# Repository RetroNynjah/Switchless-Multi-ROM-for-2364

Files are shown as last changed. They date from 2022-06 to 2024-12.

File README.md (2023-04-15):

# Retroninja Switchless Multi-ROM for 2364 ROMs

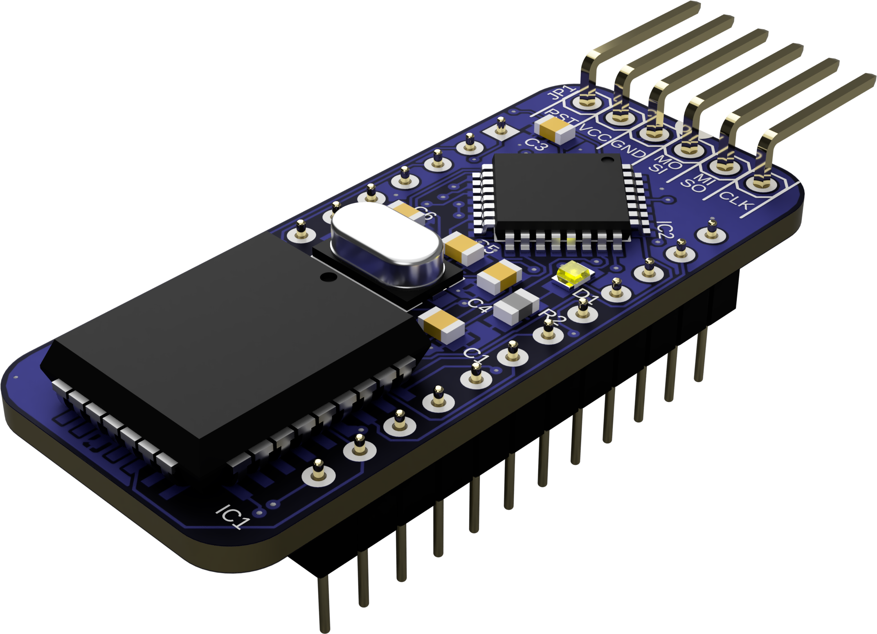
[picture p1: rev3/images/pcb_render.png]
3D rendering
<br/>

A switchless multi-ROM for 2364 ROM (24-pin) type applications. The switch is controlled by an MCU that is picking up predefined magic words on the data bus.  
This is a more generic and further developed version of my previous 1541 Multi-ROM design.

Example use cases:
* ROM switch for the Commodore 1541 disk drive controlled by DOS commands.
* Menu driven Kernal switch for Commodore C64 (longboards)
* Menu driven Kernal switch for Commodore VIC-20
* You tell me

Check the Applications folder for examples on how to use it for the use cases above.

Check the Technical Guide for a general technical description, build instructions and BOM.

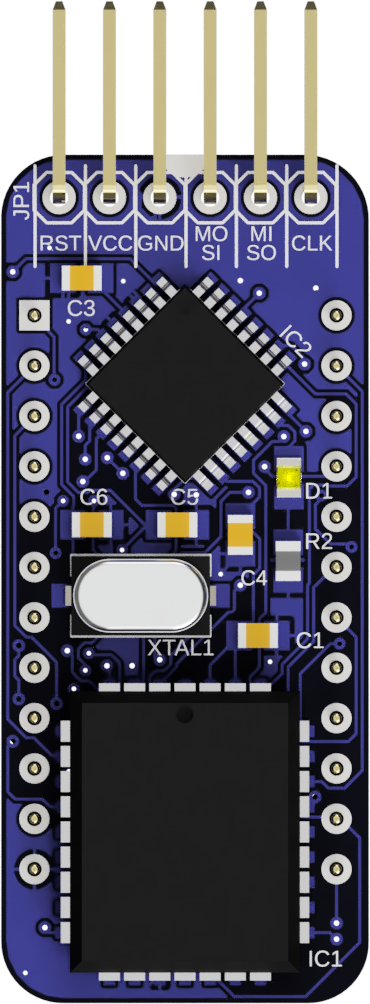
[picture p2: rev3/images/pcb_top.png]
Rendered top view
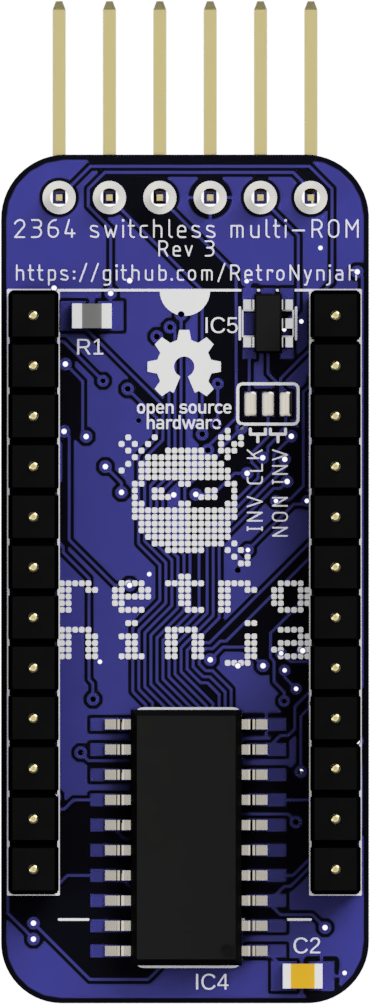
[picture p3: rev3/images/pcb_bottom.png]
Rendered bottom view
  <br/>

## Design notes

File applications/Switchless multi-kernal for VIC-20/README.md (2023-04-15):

# Switchless multi-kernal for VIC-20

Can be used as a Kernal switch for the VIC-20.  
The Kernal menu is activated by pressing the RESTORE key for a few seconds.

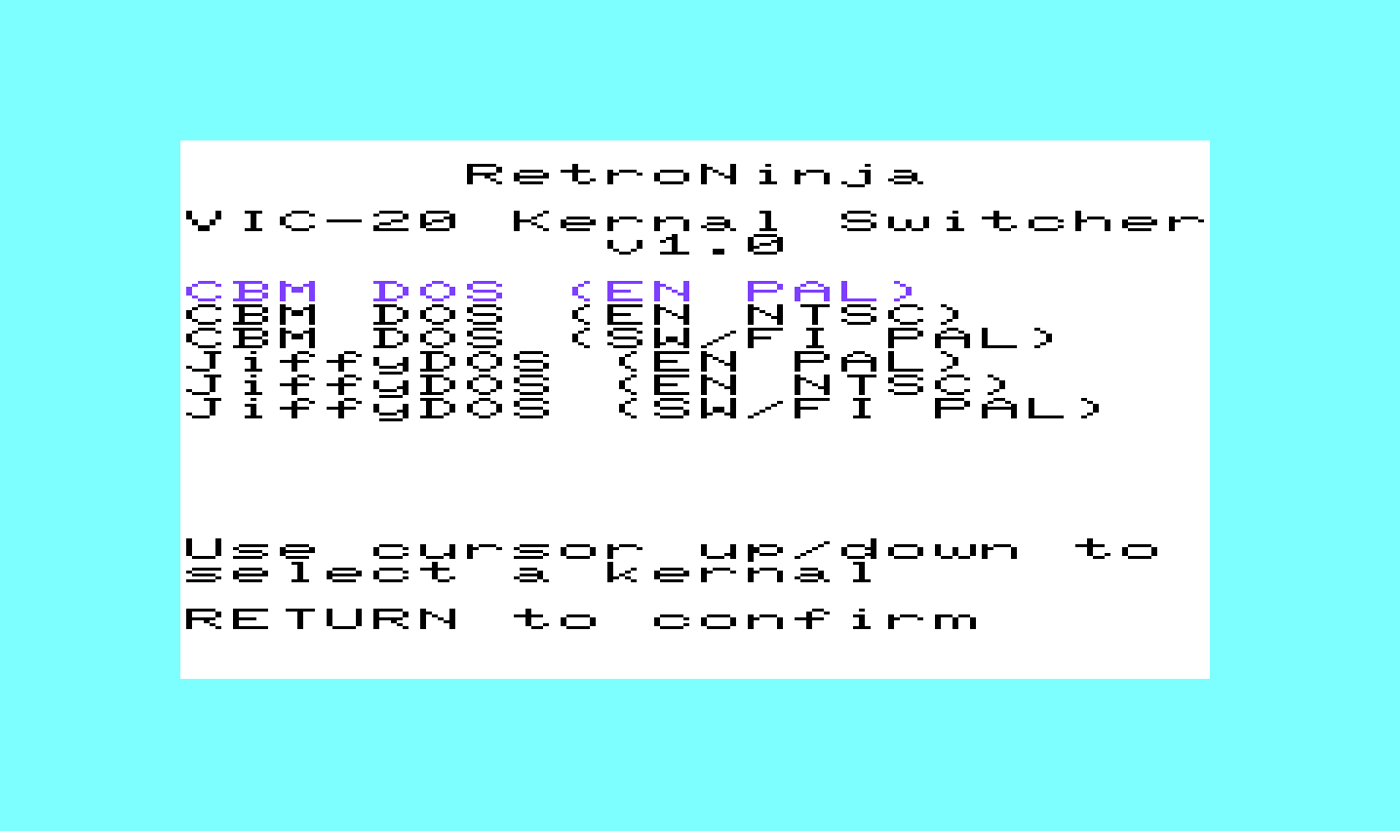
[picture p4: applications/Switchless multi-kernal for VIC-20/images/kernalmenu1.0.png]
VIC-20 Kernal menu
<br/>

Read more in the User's Guide

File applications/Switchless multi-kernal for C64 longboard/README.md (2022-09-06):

# Switchless multi-kernal for C64 longboard

Can be used as a Kernal switch for the C64 longboard motherboards.  
The Kernal menu is activated by pressing the RESTORE key for a few seconds.

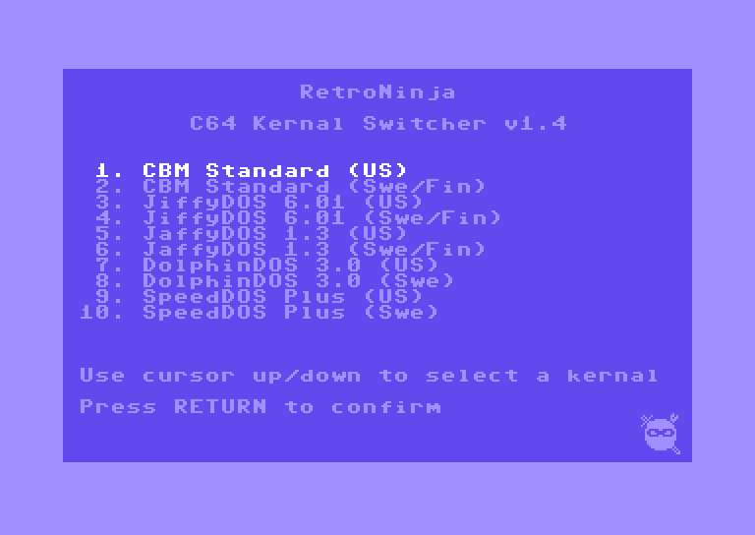
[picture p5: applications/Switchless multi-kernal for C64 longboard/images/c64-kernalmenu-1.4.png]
C64 Kernal menu
<br/>

Read more in the User's Guide

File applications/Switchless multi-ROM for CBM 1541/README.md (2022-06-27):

# Switchless multi-ROM for CBM 1541
Switches DOS ROM on the 1541 and other CBM IEC drives that uses 2364 ROMs. Can be used to switch ROM between CBM DOS/JiffyDOS/SpeedDOS/DolphinDOS and so on.

The switch is controlled by sending a command like *LOAD "2@RNROM",8* from the computer to switch to drive ROM image 2.

Read more in the User's guide.

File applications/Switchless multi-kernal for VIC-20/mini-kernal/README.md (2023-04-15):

# VIC-20 Mini-Kernal

This is the assembly source code for the VIC-20 Mini-Kernal.  
The project was created in CBM prg Studio

You need to adjust the menu to fit your needs and compile the Mini-Kernal yourself unless you are going with the exact same Kernals I did.  
Tested on both PAL and NTSC systems  

## Disclaimer:  
I'm not an assembly programmer which you should be able to tell by looking at the source. If the code doesn't work for you feel free to fix it,
If anyone wants to have a go at improving and optimizing the code you are free to do so too.

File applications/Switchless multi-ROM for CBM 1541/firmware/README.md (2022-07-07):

# Firmware

The firmware directory contains source code along with some precompiled hex files for the microcontroller.

The source code is written using the Arduino environment and can be flashed directly from Arduino using an ISP programmer.

Change log:  
1.0 - First public version for the old 1541 Multi-ROM board (rev 1, rev 1.1 & rev 2 boards) 14 May 2021  
1.1 - Updated sketch to suite the 2364 Multi-ROM board (rev 3 boards) 7 July 2022

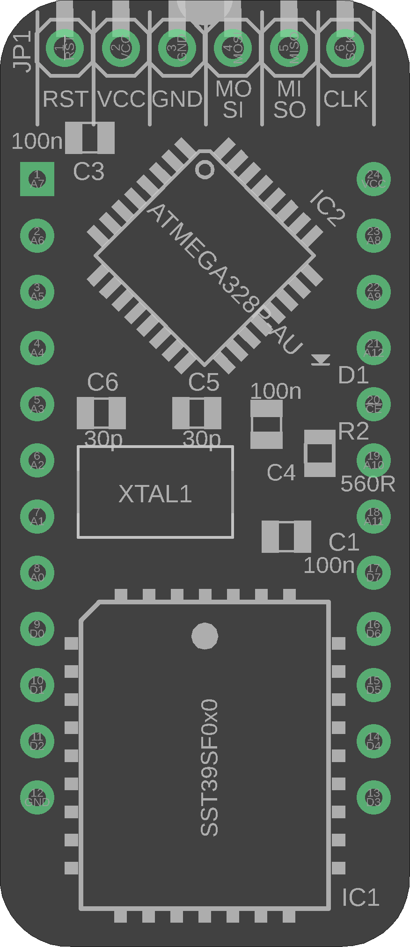
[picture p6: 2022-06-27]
rev3/images/place_top_cropped.png

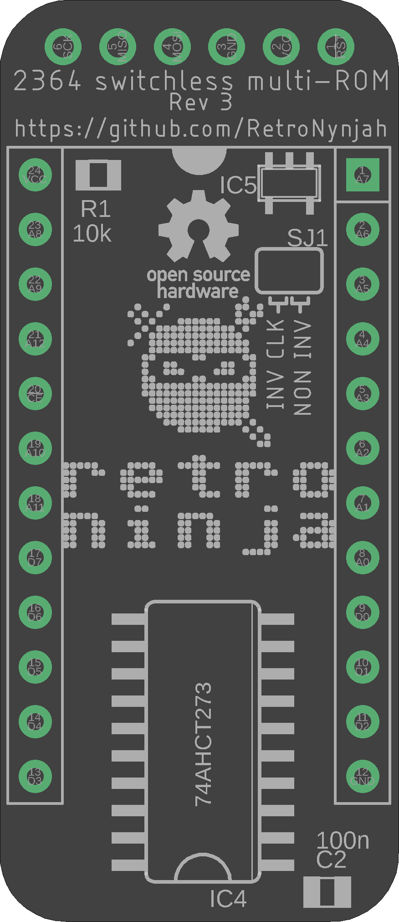
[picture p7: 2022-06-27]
rev3/images/place_bottom_cropped.png

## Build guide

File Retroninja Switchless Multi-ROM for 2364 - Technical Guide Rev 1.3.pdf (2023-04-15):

# Retroninja Switchless Multi-ROM for 2364

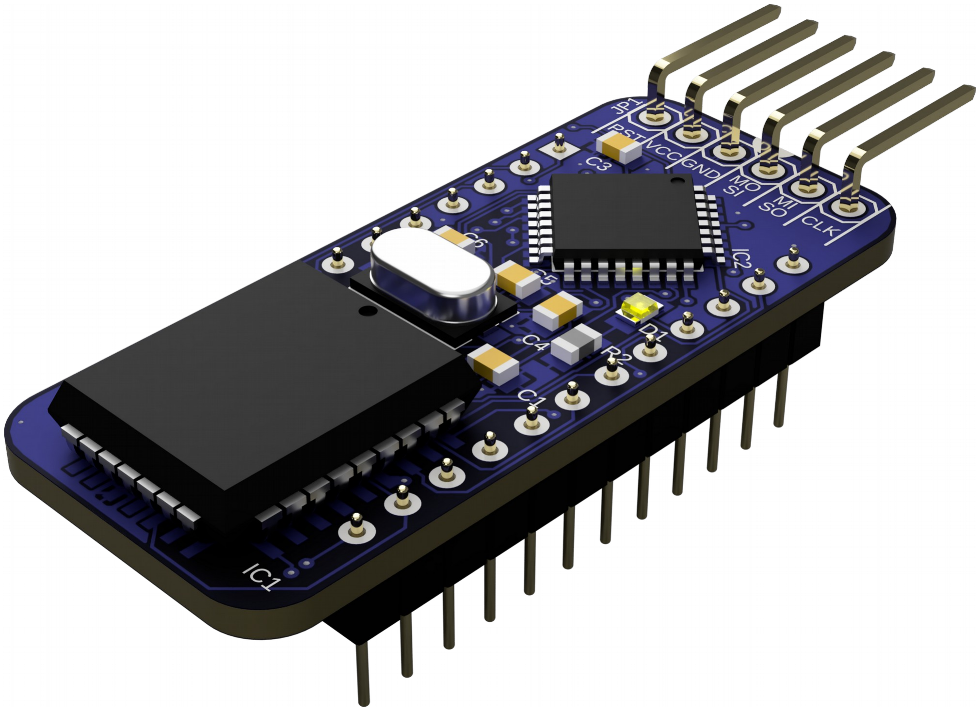
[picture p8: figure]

# Technical Guide

Retroninja Switchless Multi-ROM for 2364 | Technical Guide Version 1.3

## Table of Contents

# Background

I first created this ROM switcher as a DOS ROM switcher for the Commodore 1541 disk drive which in turn was derived from a Commodore 1541-II drive ROM switch that I had previously designed.
I realized that it can be used for a lot of other equipment that is using similar ROMs so it was re-branded and modified making the clock inverter optional.

# Theory of operation

The circuit is meant to sit in a ROM socket instead of a 24-pin 2364 ROM.
The AVR microcontroller (MCU) is connected to the data pins of the ROM socket through a flip-flop that latches the data to give the MCU more time to read the data. It's also connected to some header pins that can be connected to a clock source, a reset line and optionally other signals. It also has an on-board flash chip that contains multiple ROM images.
With the help of an external clock source, the MCU can capture bytes that are passing on the data bus and react to a predefined string of ”magic bytes” by switching the upper address pins on the flash circuit to switch to a different ROM image.
The flip-flop triggers on positive-edge of clock and if data is arriving on the bus at the negative edge of the clock signal then the clock source needs to be inverted for the flip-flop to latch the data correctly. This can be done by installing the inverter gate at IC5 and configuring solder jumper SJ1 for inverted clock.
The need for this differs between implementations depending on how the magic bytes ends up on the bus. The address pins above A12 (A13-A18) are controlled by the MCU which gives a maximum of 64*8KByte switchable ROMs.
An onboard LED can be used for diagnostic blinking or other feedback.

# Usage examples

The two use cases I've used it in is for switching JiffyDOS ROM in Commodore disk drives and Kernal in the Commodore 8-bit computers but it should be usable for other things too.

Commodore 1541 DOS ROM Switcher
The MCU source code for the 1541 ROM switch can be found under samples in the GitHub repository at: https://github.com/RetroNynjah/Switchless-Multi-ROM-for-2364
At power on, the MCU in the ROM switcher reads address 0 from its internal EEPROM to find out which ROM it should select, sets the A13-A18 address pins on the flash chip accordingly and resets the drive to make sure it’s booted with the correct image. This can be noticed when the drive is powered on and the drive initializes and stops spinning and then spins up again briefly during the switch reset.
It then starts listening for a switch command.
Even at a clock speed of 16 MHz, reading and analyzing data on a 1MHz data bus can be a challenge so the data on the 1541 data bus is buffered in the switcher by a 74AHCT273 flip-flop that is clocked by the Write signal on the 6502 MPU in the 1541. By clocking the data with the R/W signal we filter out irrelevant bus traffic and the flip-flop holds the relevant data until the next R/W cycle. This gives the MCU a little more time to read the data from the flip-flop.
The MCU listens for a predefined sequence of bytes in reverse order (MORNR@) and once the sequence is found, it treats the following numeric character as the target ROM image number. The reverse order of the characters on the bus is why the image number must be specified at the beginning of the command.

The MCU sets address pins A13-A18 on the flash chip according to image selection and it stores the ROM number at address 0 of its internal EEPROM for use at next power-on. It then resets the drive by toggling the IEC reset line.
The command can be sent from basic on a computer such as C64 or C128 by utilizing any disk drive command that contains text strings such as:

The LOAD command in the example will return a file not found error but you should see the drive switch ROM and perform a drive reset. The ROM switch LED will blink 2 times to indicate that image 2 was selected.
When building a 1541 ROM switch you should bridge the solder jumper like this:
SJ1
Inverted Clock | Non-inverted Clock

Note: To invert clock we must also install IC5

Some pins on the switch needs to be connected to the right signals in the drive. These signals can be connected to the drive using test clips but to have a secure installation it's better to solder the cables to the bottom of the PCB.
Switch pin | Drive signal
CLK | R/W (6502 pin 34)
MOSI | RESET (Middle pin of IEC DIN connector)

This switch only suits the 1541 and clones that has 24-pin ROM sockets.
1541C/1541-II drives and some clones have 28-pin 27128 type ROMs. I have another Multi-ROM version that is compatible with those in the following repository: https://github.com/RetroNynjah/Switchless-Multi-ROM-for-27128-27256

Commodore 64 longboard menu-driven Kernal switch
The MCU source code and Mini-Kernal source code for the C64 longboard kernal switch can be found under applications in the GitHub repository at:
https://github.com/RetroNynjah/Switchless-Multi-ROM-for-2364
At power on, the MCU in the Kernal switch reads address 0 from its internal EEPROM to find out which Kernal it should select, sets the A13-A18 address pins on the flash chip accordingly and resets the computer to make sure it’s booted with the correct image.
If at any time, restore is pressed and held for a few seconds the MCU will detect this and switch to Kernal 0 which is a menu Kernal. For this application I created a custom Mini-Kernal for the C64 that displays a list of Kernals to choose from.

LOAD “2@RNROM”,8

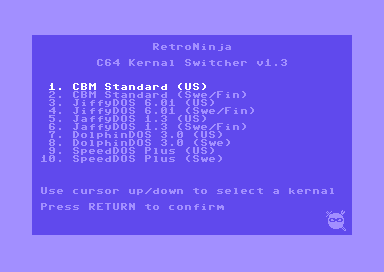
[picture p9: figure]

When the user selects a Kernal image from the menu, the Mini-Kernal writes a predefined switching command to RAM along with a byte that indicates the selected image number. It does this over and over. Example of the command: RNROM64#1 where 1 is a byte with value 0x01 that tells the switch that we want to switch to kernal image 1.
The Kernal switch now captures the command from the data bus, writes the selected kernal number to the MCU EEPROM for future use, then it switches the address pins A13-A18 accordingly. It then pulls the reset line briefly to make the computer restart using the new Kernal. The computer will continue to start up using this Kernal until a new choice is made.
The flash is populated with the Mini-Kernal followed by up to 10*8 KB Kernals. It would in theory be possible to add up to 63 kernals if both the Mini-Kernal and the MCU firmware was modified in some way to accommodate that many Kernal images.
Here's an example layout that fills out an SST39SF010A:

If the same layout would be used with a larger flash chip it should be duplicated to fill out the flash. When building a C64 kernal switch you should bridge the solder jumpers like this:
SJ1
Inverted Clock | Non-inverted Clock

Note: As we don't invert the clock we don't need to install IC5

Some pins on the switch needs to be connected to the right signals in the computer. These signals can be connected to various ICs in the computer using test clips but to have a secure installation it's better to solder the cables to vias on the PCB. See pictures in the samples directory of the GitHub repository.
Switch pin | Computer signal
CLK | R/W
MISO | RESTORE
MOSI | RESET
Mini-Kernal | CBM Kernal | JiffyDOS US | JiffyDOS SE | JiffyDOS DK | JaffyDOS US | JaffyDOS SE | SpeedDOS | SpeedDOS | DolphinDOS | DolphinDOS | Mini-Kernal | Mini-Kernal | Mini-Kernal | Mini-Kernal | Mini-Kernal
8kB | 8kB | 8kB | 8kB | 8kB | 8kB | 8kB | 8kB | 8kB | 8kB | 8kB | 8kB | 8kB | 8kB | 8kB | 8kB

This C64 Kernal switch only suits the C64 longboards which have a 24pin ROM and has basic in a separate ROM. All C64 motherboards are longboards except for PCB 250469 which can be found in newer C64C's. The C64 shortboard (PCB 250469) have 28-pin 27128 type Kernal ROMs and I have another Multi-ROM version that is compatible with those in the following repository: https://github.com/RetroNynjah/Switchless-Multi-ROM-for-27128-27256

Commodore VIC-20 menu-driven Kernal switch
The MCU source code and Mini-Kernal source code for the VIC-20 kernal switch can be found under applications in the GitHub repository at:
https://github.com/RetroNynjah/Switchless-Multi-ROM-for-2364
At power on, the MCU in the Kernal switch reads address 0 from its internal EEPROM to find out which Kernal it should select, sets the A13-A18 address pins on the flash chip accordingly and resets the computer to make sure it’s booted with the correct image.
If at any time, restore is pressed and held for a few seconds the MCU will detect this and switch to Kernal 0 which is a menu Kernal. For this application I created a custom Mini-Kernal for the VIC-20 that displays a list of Kernals to choose from.

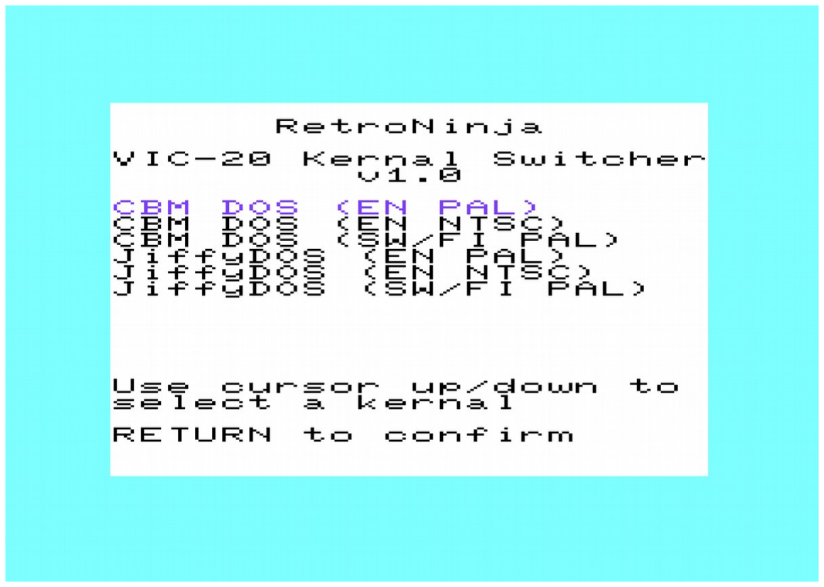
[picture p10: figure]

When the user selects a Kernal image from the menu, the Mini-Kernal writes a predefined switching command to RAM along with a byte that indicates the selected image number. It does this over and over. Example of the command: RNROM20#1 where 1 is a byte with value 0x01 that tells the switch that we want to switch to kernal image 1.
The Kernal switch now captures the command from the data bus, writes the selected kernal number to the MCU EEPROM for future use, then it switches the address pins A13-A18 accordingly. It then pulls the reset line briefly to make the computer restart using the new Kernal. The computer will continue to start up using this Kernal until a new choice is made.
The flash is populated with the Mini-Kernal followed by up to 10*8 KB Kernals. It would in theory be possible to add up to 63 kernals if both the Mini-Kernal and the MCU firmware was modified in some way to accommodate that many Kernal images.
Here's an example layout that fills out an SST39SF010A:

If the same layout would be used with a larger flash chip it should be duplicated to fill out the flash.

Mini-Kernal | CBM EN PAL | CBM EN NTSC | CBM SE PAL | Jiffy EN PAL | Jiffy EN NTSC | Jiffy SE PAL | Mini-Kernal | Mini-Kernal | Mini-Kernal | Mini-Kernal | Mini-Kernal | Mini-Kernal | Mini-Kernal | Mini-Kernal | Mini-Kernal
8kB | 8kB | 8kB | 8kB | 8kB | 8kB | 8kB | 8kB | 8kB | 8kB | 8kB | 8kB | 8kB | 8kB | 8kB | 8kB

When building a VIC-20 kernal switch you should bridge the solder jumpers like this: SJ1
Inverted Clock | Non-inverted Clock

Note: As we don't invert the clock we don't need to install IC5

Some pins on the switch needs to be connected to the right signals in the computer. These signals can be connected to various ICs in the computer using test clips but to have a secure installation it's better to solder the cables to vias on the PCB. See pictures in the samples directory of the GitHub repository.
Switch pin | Computer signal
CLK | R/W
MISO | RESTORE
MOSI | RESET

# Assembling the module

The PCB is small and a bit difficult to solder but it can be hand soldered. The reason for the small size is space constraints in some Commodore drives that this module was designed for originally. Other drives any devices may have the same constraints so keeping it small is good for compatibility.
The flash chip (PLCC) is the trickiest part to solder and If you find it hard to hand solder I recommended reflow soldering the top side using stencil and solder paste. Then solder the bottom side by hand and finally solder the pin headers.
There is a solder jumper on the bottom that must be configured.
If you configure SJ1 for inverted clock then you must also install IC5. Otherwise you can leave it out. It will only be used when SJ1 is configured for inverted clock.
Note: Don't forget to program the flash before soldering!

# Parts

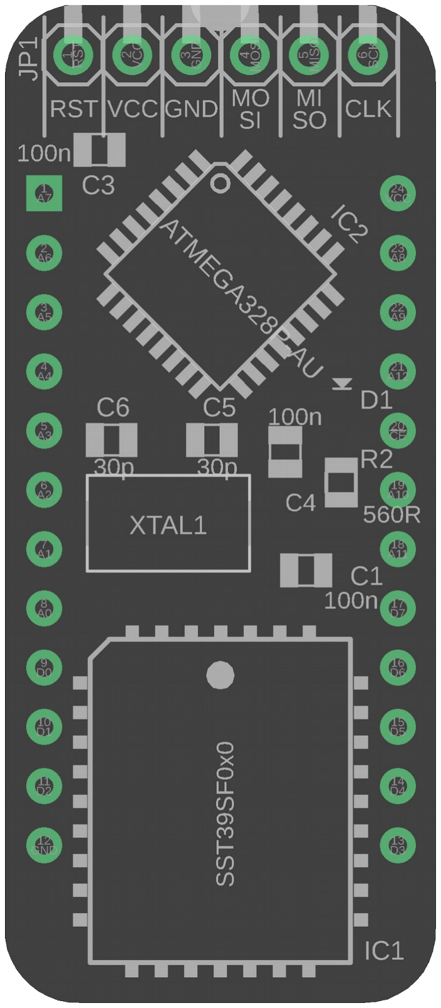
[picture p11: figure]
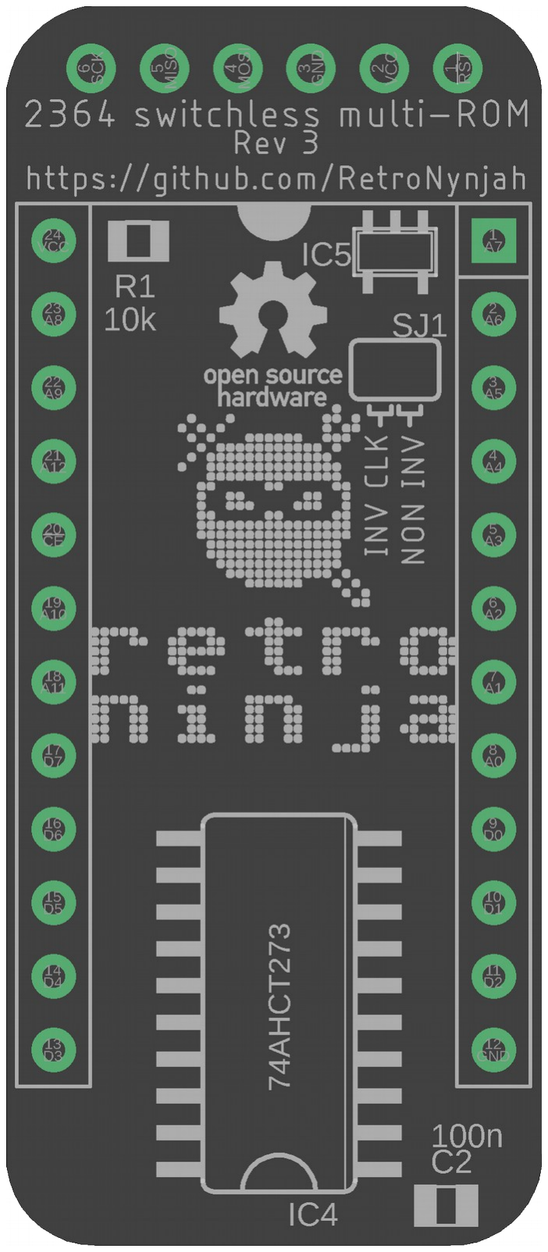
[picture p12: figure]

Top side is to the left, bottom side is to the right.
Component | Part | Description | Comment
JP1 | Header | 6-pin right-angle
D1 | LED | 0805 LED
C1, C2, C3,C4 | 100nF capacitor | 0805 ceramic capacitor
C5, C6 | 30pF capacitor | 0805 ceramic capacitor | 22pF works fine too
XTAL1 | ECS-160-20-3X-TR | 16MHz Crystal 7.0x4.1 mm
R1 | 10kΩ resistor | 0805 Resistor
R2 | 560Ω resistor | 0805 Resistor
IC1 | SST39SF0x0 | 32-PLCC Flash 4.5-5.5V | SST39SF010/20/40
IC2 | ATmega MCU | 32-TQFP MCU | Atmega48/88/168/328
IC3 | Headers | 2 header rows, 14 pin | Use machined or flat pins - not square
IC4 | 74AHCT273 | 20-SOIC 5.3mm Flip-Flop
IC5 | 741G04 | SOT23-5 1 x Inverter | Only needed if clock needs inverting
The ATmega model is not critical. The firmware requires less than 2KB of MCU flash. I have tested Atmega48, 48A, 48PA, 88A, 328P and they have worked for me. Any other pin-compatible ATmega could work too depending on your application.

# Programming the microcontroller

The firmware can be flashed using the 6-pin ISP header. The source code is written for Arduino and programming the firmware can be done directly from the Arduino IDE using an ISP programmer.
If you are using an Atmega328 it can be programmed as an Arduino UNO. The other variants require custom board definitions. I have used the MiniCore from MCUdude (https://github.com/MCUdude/MiniCore) with default board settings.
If you can't or don't want to use Arduino I have some precompiled hex files for the Kernal switch and drive ROM switch along with fuse configurations and syntax examples for how to program them using avrdude. These can be found under the Examples folder in my GitHub repository.

# Programming the flash chip (ROM)

The flash chip needs to be programmed before soldering it. If you need to reprogram the flash later it must first be desoldered and then resoldered again after reprogramming.
You need to concatenate all your images into one file and fill up any empty space in flash with valid extra images to avoid bricking your host device if an incorrect image number is selected. If that would happen the EEPROM can be reset by re-flashing the firmware.
All images must be 8kB in size.

# Document revision history

1.0 Initial version
1.1 Cover page image corrected
1.2 BOM Corrected
1.3 VIC-20 Kernal switch section added

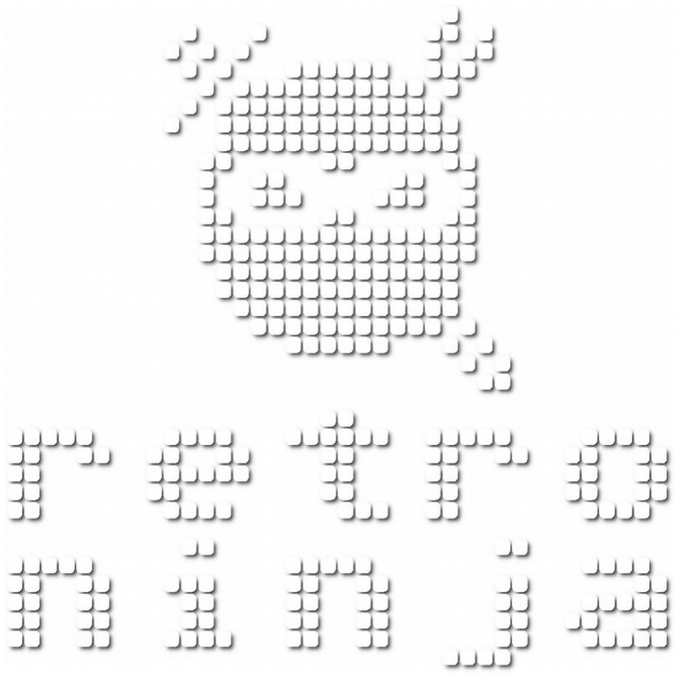
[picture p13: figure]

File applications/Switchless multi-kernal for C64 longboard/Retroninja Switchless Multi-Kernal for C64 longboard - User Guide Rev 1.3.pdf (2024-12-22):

# Retroninja Switchless Multi-Kernal for C64 longboard

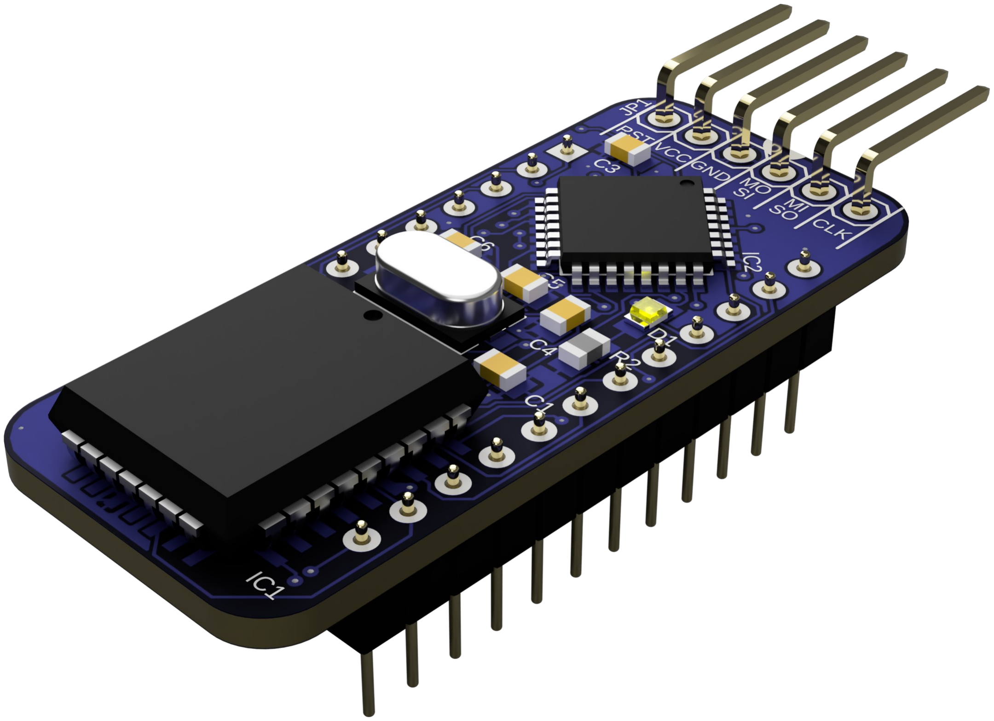
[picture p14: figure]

# User Guide

Retroninja Switchless Multi-Kernal for C64 longboard | User Guide Version 1.3

## Table of Contents

# Functional description

t power on, the MCU in the Kernal switch holds the reset line active while it reads address 0 from its internal EPROM to find out which Kernal it should select, sets the A13-A18 address pins on the flash chip accordingly and releases the reset line to make sure the computer is booted using the correct Kernal.
If at any time, restore is pressed and held for a few seconds the MCU will detect this and switch to Kernal 0 which is a menu Kernal. For this application I created a custom Mini-Kernal for the C64 that displays a list of Kernals to choose from.


When the user selects a Kernal image from the menu, the Mini-Kernal writes a predefined switching command to RAM along with a byte that indicates the selected image number. It does this over and over. Example of the command: RNROM64#1 where 1 is a byte with value 0x01 that tells the switch that we want to switch to kernal image 1.
The Kernal switch now captures the command from the data bus, writes the selected kernal number to the MCU EPROM for future use, then it switches the address pins A13-A18 accordingly. It then resets the computer using the new Kernal by pulling the reset line. The computer will continue to start up using this new Kernal until a new choice is made.
The flash is populated with the Mini-Kernal followed by up to 10*8 KB Kernals. It would in theory be possible to add up to 63 kernals if both the Mini-Kernal and the MCU firmware was modified in some way to accommodate that many Kernal images.
Here's an example layout that fills out an SST39SF010A:

If the same layout would be used with a larger flash chip it should be duplicated to fill out the flash.
This C64 Kernal switch only suits the C64 longboards which have a 24pin ROM and has basic in a separate ROM. All C64 motherboards are longboards except PCB 250469.
The C64 shortboard (PCB 250469) have 28-pin 27128 type Kernal ROMs and I have another Multi-ROM version that is compatible with those at: https://github.com/RetroNynjah/Switchless-Multi-ROM-for-27128-27256
Mini-Kernal | CBM Kernal | JiffyDOS US | JiffyDOS SE | JiffyDOS DK | JaffyDOS US | JaffyDOS SE | SpeedDOS | SpeedDOS | DolphinDOS | DolphinDOS | Mini-Kernal | Mini-Kernal | Mini-Kernal | Mini-Kernal | Mini-Kernal
8kB | 8kB | 8kB | 8kB | 8kB | 8kB | 8kB | 8kB | 8kB | 8kB | 8kB | 8kB | 8kB | 8kB | 8kB | 8kB

# Installing the Kernal switch

The switch will replace the kernal ROM chip U4.
U4 is not always socketed and if it isn't it must first be desoldered from the board and a 24 pin socket should be soldered to the board before the switch is installed. Pay attention to the direction of the notch on U4 that indicates the location of pin 1. The notch on the socket should face the same direction and so should pin 1 on the switch. Pin 1 on the switch is at the end that has six header pins. It is also indicated by a printed notch on the bottom side of the switch.
If any EPROM adapters are installed at U4 they need to be removed and the switch should be installed directly in the socket
The below pins on the switch must be connected to the right signals on the motherboard.
Switch pin | Computer signal | Example of locations
CLK | R/W | 6510 pin 38, 6526 pin 22
MISO | RESTORE | KBD connector pin 3
MOSI | RESET | 6510 pin 40, 6526 pin 34
The connections can be made on the chips using test clips but it's recommended to solder pin headers to vias on the motherboard and connect to the pin headers using Dupont wires or solder one end of Dupont cables directly to the vias for a permanent installation.
If you want to solder pin headers to the vias you can try inserting them from the top side without taking the board out. Try heating the pins with the soldering iron while pushing them into the via using pliers but to get the best possible connection of the pins they should be soldered from the bottom of the motherboard. The below pictures show examples of suitable vias for different motherboards.

PCB 251022 / KU-14194HB

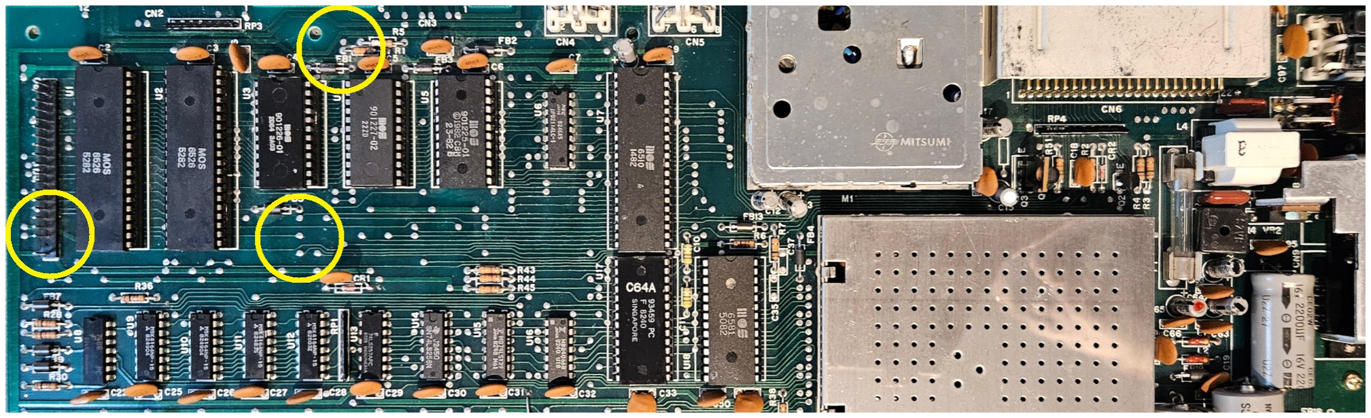
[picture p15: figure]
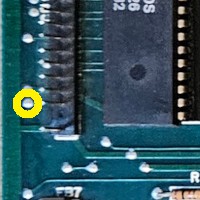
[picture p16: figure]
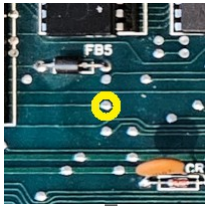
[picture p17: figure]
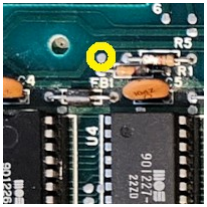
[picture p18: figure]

ORE | R/W | RESET

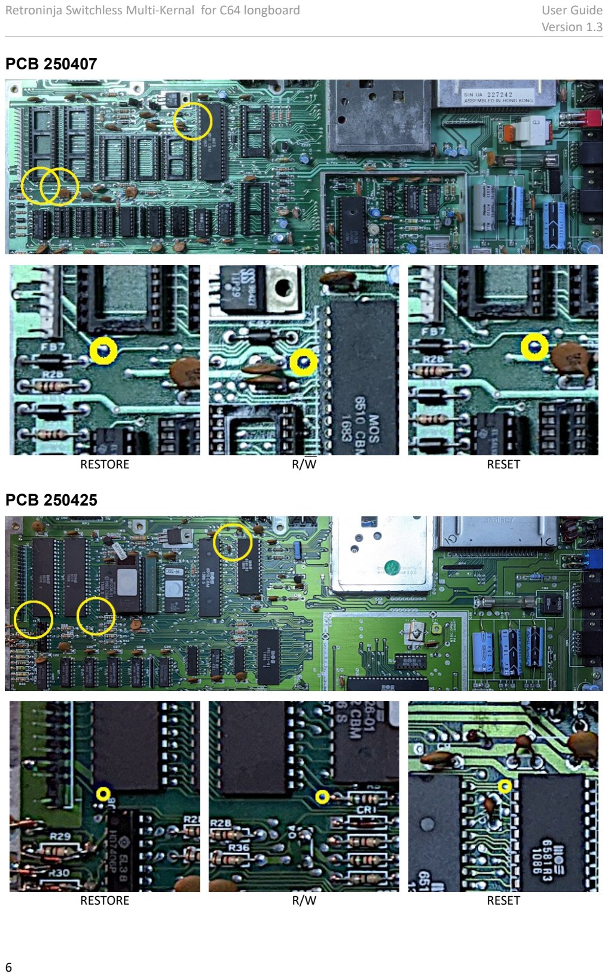
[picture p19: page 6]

PCB 250407

RESTORE | R/W | RESET

PCB 250425

RESTORE | R/W | RESET

PCB 250466

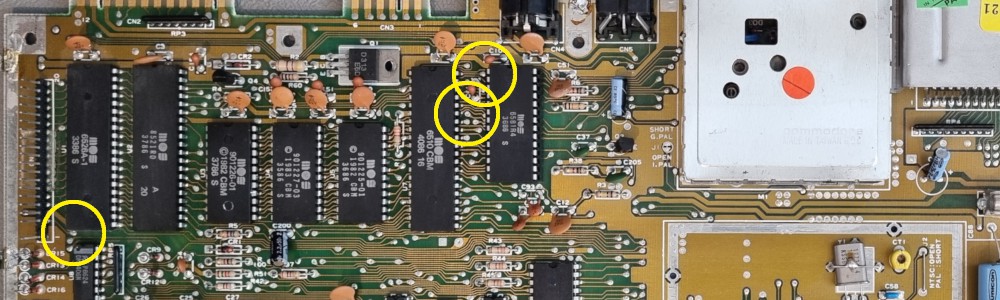
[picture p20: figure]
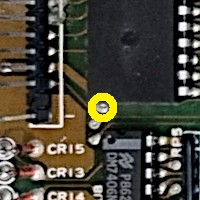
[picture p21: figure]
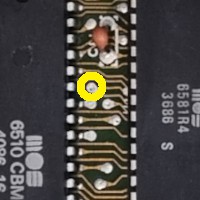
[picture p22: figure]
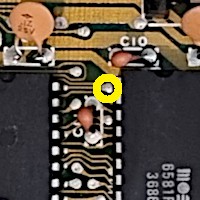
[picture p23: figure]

RESTORE | R/W | RESET

# Using the Kernal switch

Hold the restore key for about three seconds until the kernal menu is activated. Once in menu you can use cursor up/down to move to the Kernal you want to switch to and press return. The switch resets the computer with the new Kernal and saves your choice for next power-on.

# Upgrading the firmware

The firmware in the microcontroller can be upgraded using the 6-pin ISP header. The source code is written for Arduino and programming the firmware can be done directly from the Arduino IDE using an ISP programmer.
If your device is using an Atmega328 it can be programmed as an Arduino UNO. The other variants require custom board definitions. I have used the MiniCore from MCUdude (https://github.com/MCUdude/MiniCore) with default board settings.
If you can't or don't want to use Arduino I have some precompiled hex files for the Kernal switch and drive ROM switch along with fuse configurations and syntax examples for how to program them using avrdude. These can be found under the Applications folder in the GitHub repository at: https://github.com/RetroNynjah/Switchless-Multi-ROM-for-2364

# Programming the flash chip (ROM)

The flash chip needs to be programmed before soldering it. If you need to reprogram the flash later it must first be desoldered and then resoldered again after reprogramming.The flash chip should contain the Mini-Kernal image followed by all switchable kernal images in correct order.
All images needs to have a size of exactly 8KB.

# Document revision history

1.0 Initial version
1.1 Cover page image corrected
1.2 Added Kernal ROM location/socket information
1.3 Added PAL Rev A motherboard with no PCB Assy number but with FAB number 251022 REV B. Often (incorrectly) called KU-14194HB.

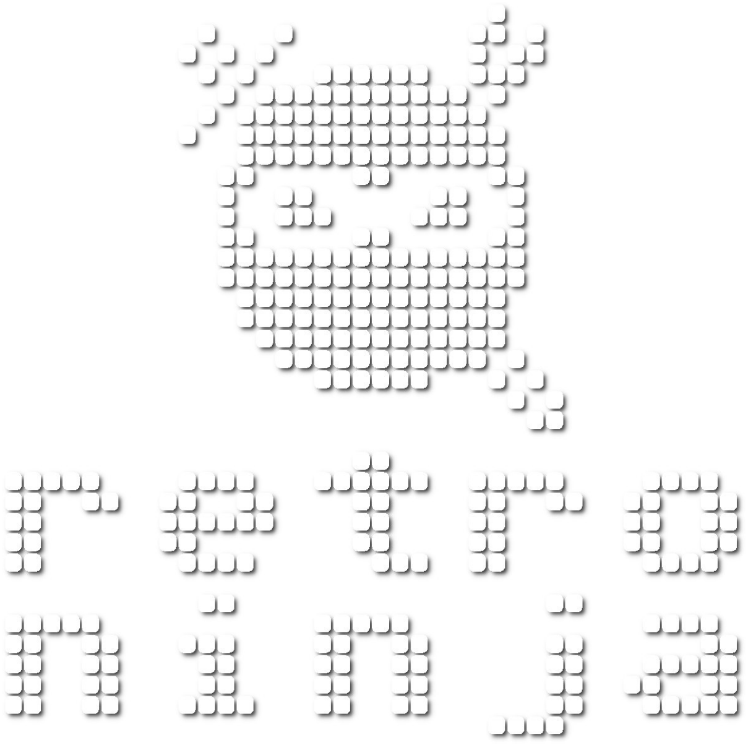
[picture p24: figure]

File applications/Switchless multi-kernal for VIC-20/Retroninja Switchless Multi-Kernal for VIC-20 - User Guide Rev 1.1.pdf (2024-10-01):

# Retroninja Switchless Multi-Kernal for VIC-20


# User Guide

Retroninja Switchless Multi-Kernal for VIC-20 | User Guide Version 1.1

## Table of Contents

# Functional description

At power on, the MCU in the Kernal switch holds the reset line active while it reads address 0 from its internal EPROM to find out which Kernal it should select, sets the A13-A18 address pins on the flash chip accordingly and releases the reset line to make sure the computer is booted using the correct Kernal.
If at any time, restore is pressed and held for a few seconds the MCU will detect this and switch to Kernal 0 which is a menu Kernal. For this application I created a custom Mini-Kernal for the VIC-20 that displays a list of Kernals to choose from.


When the user selects a Kernal image from the menu, the Mini-Kernal writes a predefined switching command to RAM along with a byte that indicates the selected image number. It does this over and over. Example of the command: RNROM20#1 where 1 is a byte with value 0x01 that tells the switch that we want to switch to kernal image 1.
The Kernal switch now captures the command from the data bus, writes the selected kernal number to the MCU EPROM for future use, then it switches the ROM address pins A13-A18 accordingly. It then resets the computer using the new Kernal by pulling the reset line. The computer will continue to start up using this new Kernal until a new choice is made.
The flash is populated with the Mini-Kernal followed by up to 10*8 KB Kernals. It would in theory be possible to add up to 63 Kernals if both the Mini-Kernal and the MCU firmware was modified in some way to accommodate that many Kernal images.
Here's an example layout that fills out an SST39SF010A:

If the same layout would be used with a larger flash chip it should be duplicated to fill out the flash.

Mini-Kernal | CBM EN PAL | CBM EN NTSC | CBM SE PAL | Jiffy EN PAL | Jiffy EN NTSC | Jiffy SE PAL | Mini-Kernal | Mini-Kernal | Mini-Kernal | Mini-Kernal | Mini-Kernal | Mini-Kernal | Mini-Kernal | Mini-Kernal | Mini-Kernal
8kB | 8kB | 8kB | 8kB | 8kB | 8kB | 8kB | 8kB | 8kB | 8kB | 8kB | 8kB | 8kB | 8kB | 8kB | 8kB

# Installing the Kernal switch

The switch will replace the kernal ROM chip (UD6 on Rev E boards, UE12 on boards 324003/250403).
The kernal ROM chip is not always socketed and if it isn't, it must first be desoldered from the board and a 24 pin socket should be soldered to the board before the switch is installed. Pay attention to the direction of the notch on the chip that indicates the location of pin 1. The notch on the socket should face the same direction and so should pin 1 on the switch. Pin 1 on the switch is at the end that has six header pins. It is also indicated by a printed notch on the bottom side of the switch.
If any EPROM adapters are installed at positionUD6/UE12 they need to be removed and the switch should be installed directly in the socket
The below pins on the switch must be connected to the right signals on the motherboard.
Switch pin | Computer signal | Example of locations
CLK | R/W (CRW) | 6502 pin 34, 6522 pin 22
MISO | RESTORE | KBD connector pin 3
MOSI | RESET | 6502 pin 40
The connections can be made on the chips using test clips but it's recommended to solder pin headers to vias on the motherboard where available and connect the pin headers using Dupont wires or solder a cable to the motherboard for a permanent installation. If you want to solder pin headers to the vias you can try inserting them from the top side without taking the board out. Try heating the pins with the soldering iron while pushing them into the via using pliers but to get the best possible connection of the pins they should be soldered from the bottom of the motherboard.
The pictures in the following sections show examples of suitable vias for different motherboards.

PCB 250403
TBD

PCB 251037

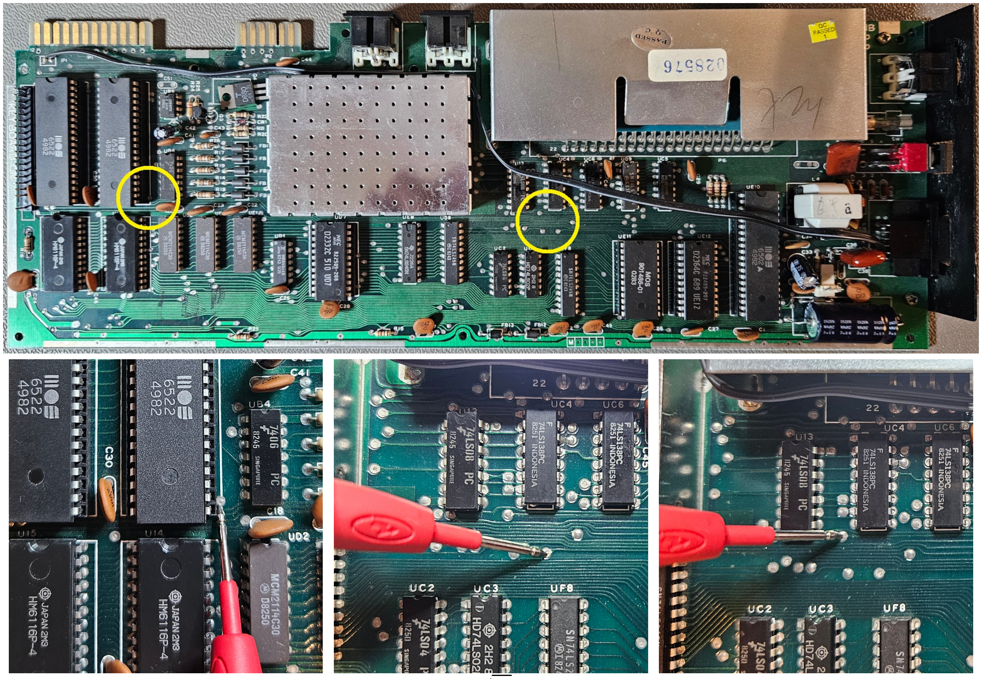
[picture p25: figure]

RESTORE | R/W | RESET

PCB 324003

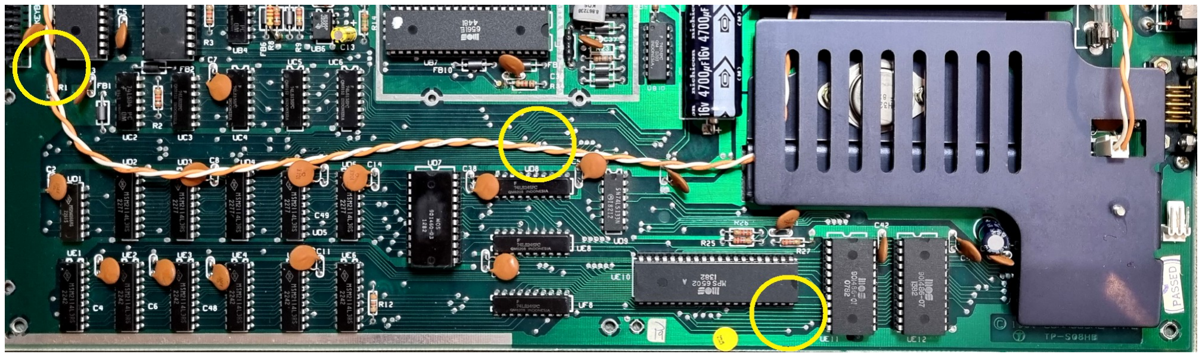
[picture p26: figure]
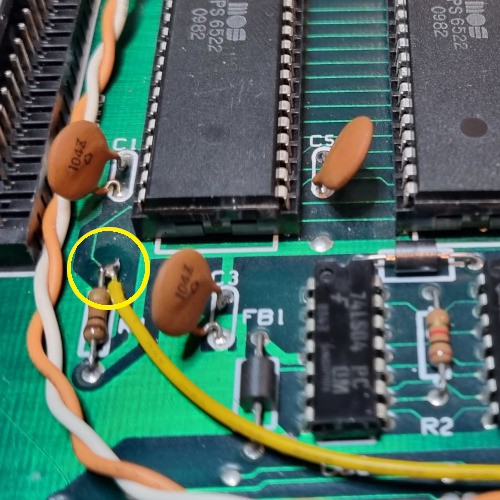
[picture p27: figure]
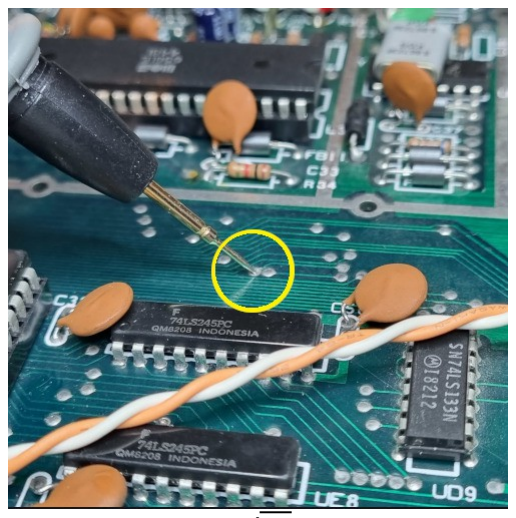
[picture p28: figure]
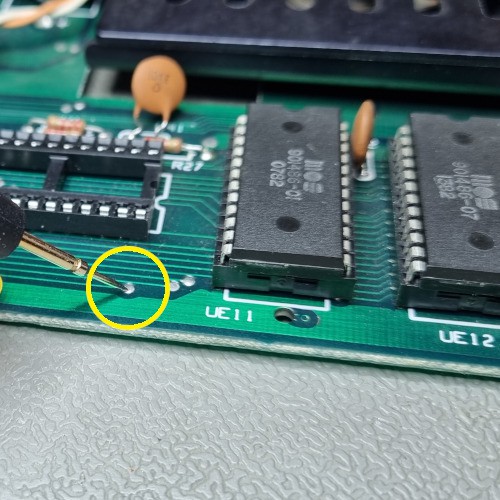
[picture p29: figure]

RESTORE | R/W | RESET
The restore signal doesn't go through any VIAs on this PCB. Solder the restore wire to the upper end of resistor R1 or solder it to the bottom of the PCB. Pin 40 of VIA UAB3 is the point closest to the ROM socket. Make sure none of the header pins on the switch touches the heat sink.

# Using the Kernal switch

Hold the restore key for about three seconds until the kernal menu is activated. Once in menu you can use cursor up/down to move to the Kernal you want to switch to and press return. The switch resets the computer with the new Kernal and saves your choice for next power-on.

# Upgrading the firmware

The firmware in the microcontroller can be upgraded using the 6-pin ISP header. The source code is written for Arduino and programming the firmware can be done directly from the Arduino IDE using an ISP programmer.
If your device is using an Atmega328 it can be programmed as an Arduino UNO. The other variants require custom board definitions. I have used the MiniCore from MCUdude (https://github.com/MCUdude/MiniCore) with default board settings.
If you can't or don't want to use Arduino I have some precompiled hex files for the Kernal switch and drive ROM switch along with fuse configurations and syntax examples for how to program them using avrdude. These can be found under the Applications folder in the GitHub repository at: https://github.com/RetroNynjah/Switchless-Multi-ROM-for-2364

# Programming the flash chip (ROM)

The flash chip needs to be programmed before soldering it. If you need to reprogram the flash later it must first be desoldered and then resoldered again after reprogramming.
The flash chip should contain the Mini-Kernal image followed by all switchable kernal images in correct order. All images needs to have a size of exactly 8KB.

# Document revision history

1.0 Initial version
1.1 Added PCB 251037, minor corrections

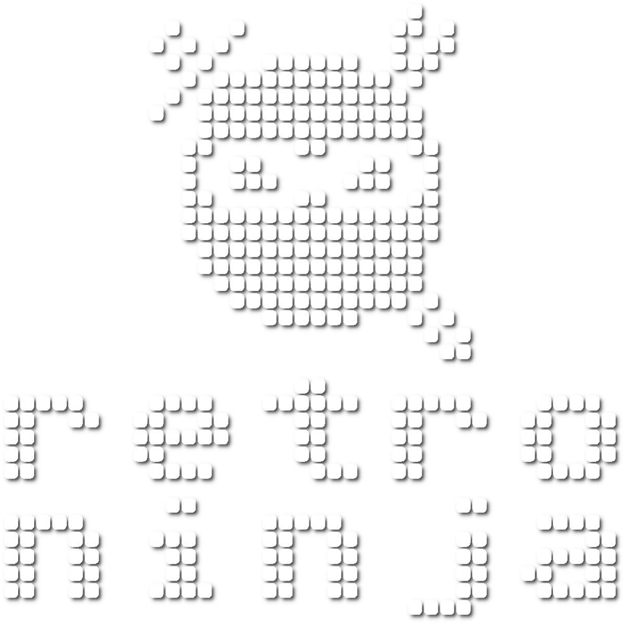
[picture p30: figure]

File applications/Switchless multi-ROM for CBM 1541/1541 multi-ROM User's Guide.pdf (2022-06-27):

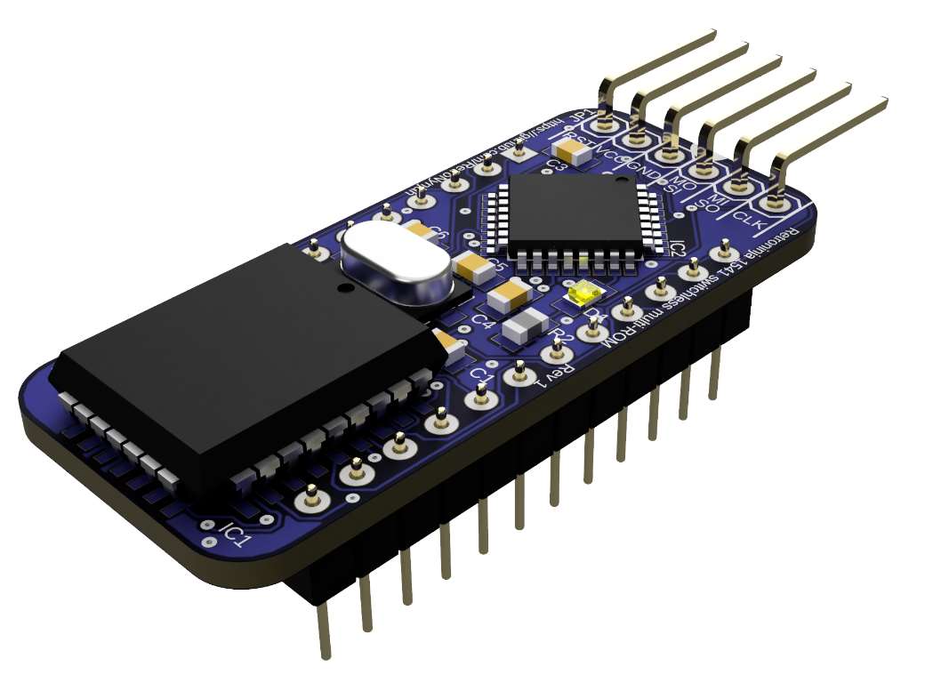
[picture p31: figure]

P a g e 1 | 6

# Switchless Multi-ROM for CBM 1541 User’s Guide

This microcontroller-based switchless ROM-switcher for the 1541 disk drive lets you switch drive ROM between stock CBM DOS and JiffyDOS using simple basic commands.
It’s possible to use other DOS versions too as long as only the upper half of the ROM set ($E000) needs switching as with JiffyDOS.

## Usage

The switcher is listening to the data bus for a predefined word and a number. The easiest way to send the word to the drive is to issue a load command to the drive from basic with the word as filename.
The default magic word is #@RNROM where # is the number of the ROM image you want to switch to.
LOAD “1@RNROM”,8 switches drive 8 to DOS image 1 and LOAD “2@RNROM”,8 switches to image 2 and so on. The default valid range of numbers is 1-8. It is possible to modify the code to allow bigger numbers but the amount of available ROMs on the market is not that large.
The drive will respond with a file not found error but the programmer will pick up the command, blink the multi-ROM LED to indicate which image was selected, switch the ROM by setting the high address pins accordingly and reset the drive using the newly selected ROM.
The selected ROM will be remembered and used at power-on.

Retroninja 1541 switchless multi-ROM | User’s Guide version 1.1
P a g e 2 | 6

## Theory of operation

At power on, the microcontroller in the ROM switcher reads address 0 from its internal EPROM to find out which ROM it should select, sets the address A13-A16 on the flash chip and resets the drive to make sure it is booted with the correct image. This can be noticed when the drive is powered on and the drive initializes and stops spinning and then spins up again briefly during the switch reset. It then starts listening for a switch command.
Even at a clock speed of 16 MHz, reading and analyzing a 1MHz data bus can be a challenge so the data on the 1541 data bus is buffered in the switcher by a 74AHCT273 flip-flop that is clocked by the Write signal on the 6502 MPU in the 1541. By clocking the data with the R/W signal we filter out irrelevant bus traffic and the flip-flop holds the data until the next write cycle. This gives the microcontroller enough time to read the data from the flip-flop.
The microcontroller listens for a predefined sequence of bytes in reverse order (MORNR@) and once the sequence is found, it treats the following numeric character as the target ROM image number. The reverse order of the characters on the bus is why the image number must be specified at the beginning of the command.
The microcontroller sets address pins A13-A16 on the flash chip according to image selection and it stores the ROM number at address 0 of its internal EPROM for use at next power-on. It then resets the drive by toggling the IEC reset line.

P a g e 3 | 6

## Building the circuit

The switcher is small and a bit difficult to solder but it can be hand soldered. The reason for the small size is space constraints in some drives. This design started off as a Multi-ROM for the 1541-II which has even less space around the ROM. You can find that version among my other repositories on GitHub.
The Flash chip is the trickiest part to solder and I recommended reflow soldering the top side using stencil and solder paste. Then solder the bottom side by hand and finally solder the pin headers.

### Parts

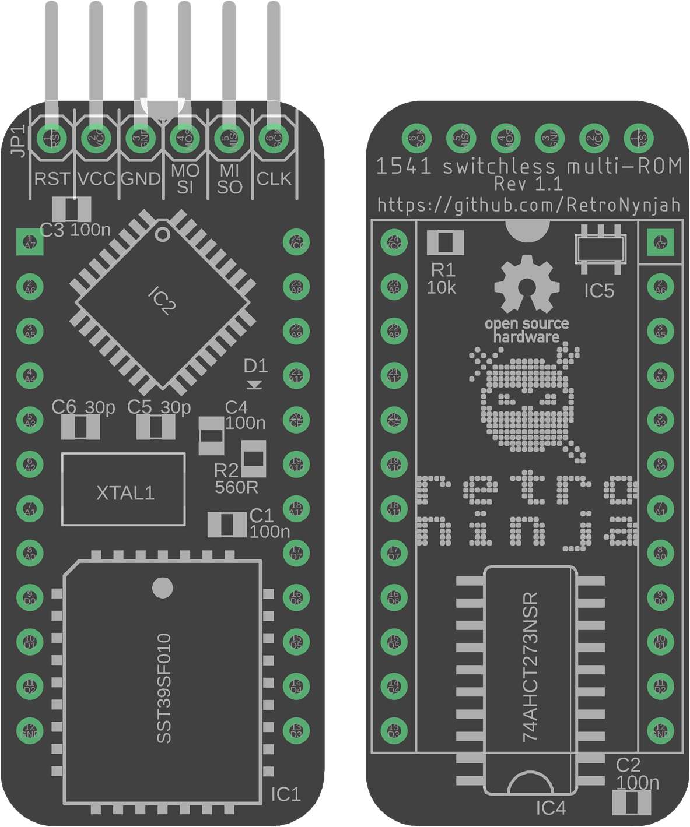
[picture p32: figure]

The switcher is designed for the SST39SF010A flash chip but the bigger SST39SF020/SST39SF040 could be used too if no SST39SF010A is available. Remember to duplicate the flash contents to fill all of flash to prevent floating pins from switching to empty flash areas.
The microcontroller does not have to be an ATmega328P but it is much easier if you want to program it from the Arduino IDE as it will be seen as an Arduino UNO.
It could be possible to replace it with other compatible MCUs such as variations of ATmega8/48/88/168/328 if you find or create the right Arduino board definitions for compiling the firmware. The chip needs to be pin-compatible with the ATmega328P TQFP-32 and capable of running at 16MHz so the V and PB variations will not work. I have used the ATmega88A.
The flip-flop needs to be a 74AHCT273. LS/HCT/AHC or any other variant will most likely not work.

P a g e 4 | 6

The 74AHCT1G04 single gate inverter is needed for inverting the active low write signal from the 6502 to the active high clock input of the flip-flop.
The crystal should be a 16MHz crystal but 20 MHz might work too if you recompile the sketch and burn the fuses accordingly. Not tested.
The LED on the board is optional but flashes a number of times indicating the number of the selected ROM when switching. It is only there for debugging reasons.
The pin headers that goes into the ROM socket should have round machined pins or be of that long flat type that is used for the pass-through pin headers on Arduino shields.
Square pin headers destroy the ROM socket in the drive.

### Programming the microcontroller

The recommended microcontroller for this board is an ATmega328P. The code for the controller was created using the Arduino environment and the device can be programmed in circuit from a sketch in the Arduino IDE using an ISP programmer. The board type can be set to Arduino UNO.
It can be programmed using AVRDUDE and the pre-compiled HEX file or using the popular TL866II programmer. The pin-out of the programming pins on the PCB matches the pin-out of the TL866II ICSP connector so a straight 6-pin cable can be used.
If you use an ATmega328P, the fuse settings should be the same as for an Arduino UNO. lfuse=0xFF, hfuse=0xDE, efuse=0xFD
How to use an Arduino as ISP or how to use an ISP programmer such as a USBASP will not covered by this document.

### Programming the flash chip

Due to space constraints, there are no on-board programming headers for the flash chip so the flash chip must be programmed in a flash/EPROM programmer before soldering it to the board or desoldered for reprogramming.
It could also be possible to make a programming adapter to put on top of the flash chip to program it while it’s still soldered to the board but this is not tested.
The high ROM chip in the 1541 is only 64 kbit (8 kilobyte) while the flash chip is 1 Mbit (128 kilobyte). It’s highly recommended to fill the entire flash chip with working DOS images to prevent bricking of the drive by selecting a non-existing image. The switcher will not work without a working ROM in the drive that can receive the serial data and put it on the data bus.
If you just use two ROM images, fill the flash with the same two images over and over for safety.

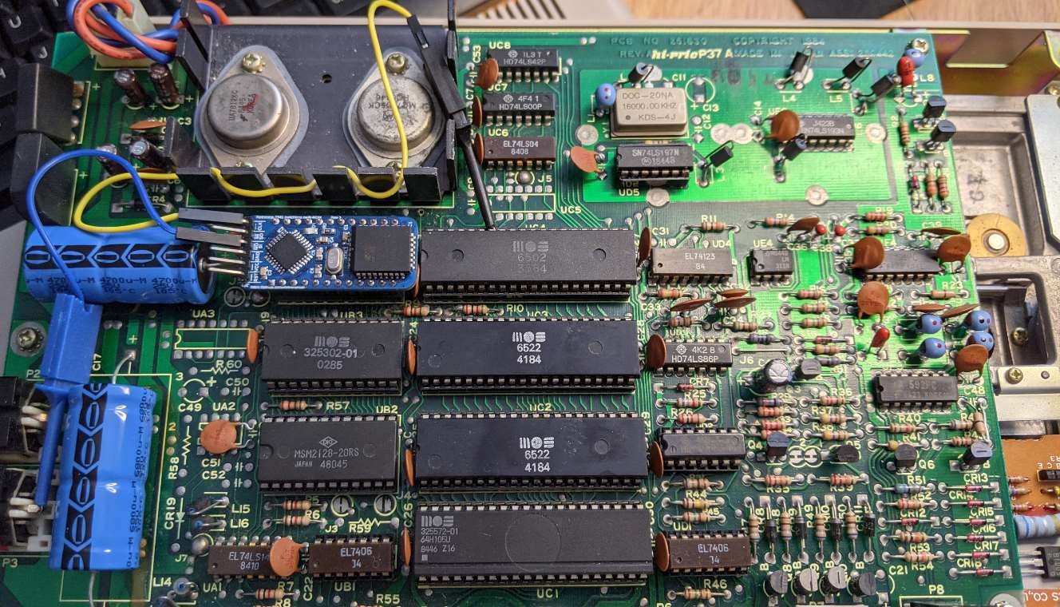
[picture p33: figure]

P a g e 5 | 6

## Installation

The circuit can be installed in the drive without soldering by using DuPont cables with test clips that attaches to the R/W pin on the 6502 MPU and to the reset pin on the back of any of the IEC connectors. However, it is recommended to solder the cables to the pins on the bottom of the drive PCB. That makes for a much more robust and transportable solution.
An even more stable solution is to solder the cables to the edge of the switcher PCB instead of using a pin header but that could make it harder to upgrade the firmware in the future.
The edge of the Multi-ROM PCB with the six ISP pins should face the notched end of the ROM socket (Pin 1). You may have to bend a ceramic capacitor out of the way a little before you can insert it.

The clock signal (CLK on the Multi-ROM) connects to the R/W pin (pin 34) on the 6502 MPU.
MOSI on the Multi-ROM connects to IEC reset. That’s the center pin on the back of the IEC connectors. The Multi-ROM works without a connection to IEC reset but a manual drive reset would then be needed after switching ROM.
The sketch and a pre-compiled firmware for the Multi-ROM can be found at https://github.com/RetroNynjah/1541-Switchless-Multi-ROM

## Troubleshooting

If the device becomes bricked due to an incorrect DOS image, program the ATmega with a sketch that sets byte 0 to 0x00 or 0xFF in the internal EPROM. Then upload the original Multi-ROM sketch again and you should be back on track.
Switching may not work if you are using a fast loader such as Action Replay in your computer. Try switching the ROM without the fast loader. Switching ROM using JiffyDOS in the C64 is working fine though.

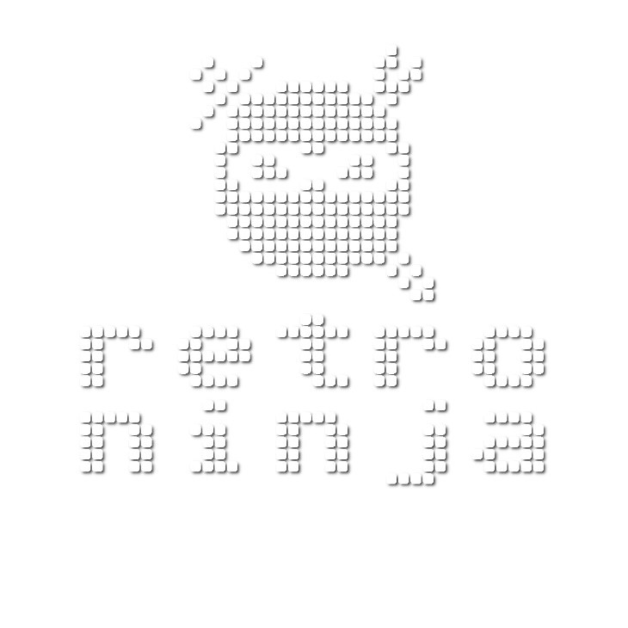
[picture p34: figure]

P a g e 6 | 6

## Possible other uses

A second switcher for the low ROM in the 1541 could be used simultaneously if you need to switch both ROMs simultaneously or maybe use a slave 2364 ROM adapter for the low ROM and connect the unused address A13-A16 to the same address pins on the Switchless Multi-ROM using bodge wire or similar.
The switcher could possibly be used for other 2364 ROM switching applications if you can find the right clock signal and strings to listen for.
The switcher could work in other 1541 compatible drives that are using 2364 ROMs but none have been tested so far. The 1541-II switcher emulates a 16kB 27128 EPROM has been tested in a number of compatible drives.

## Change history

This is the change history for the user’s guide.
For changes to the schematics, PCB or firmware, please refer to the GitHub repository at https://github.com/RetroNynjah/1541-Switchless-Multi-ROM
Date | Version | Description
2021-05-15 | 1 | Initial version
2021-05-22 | 1.1 | Alternative ATmega MCUs

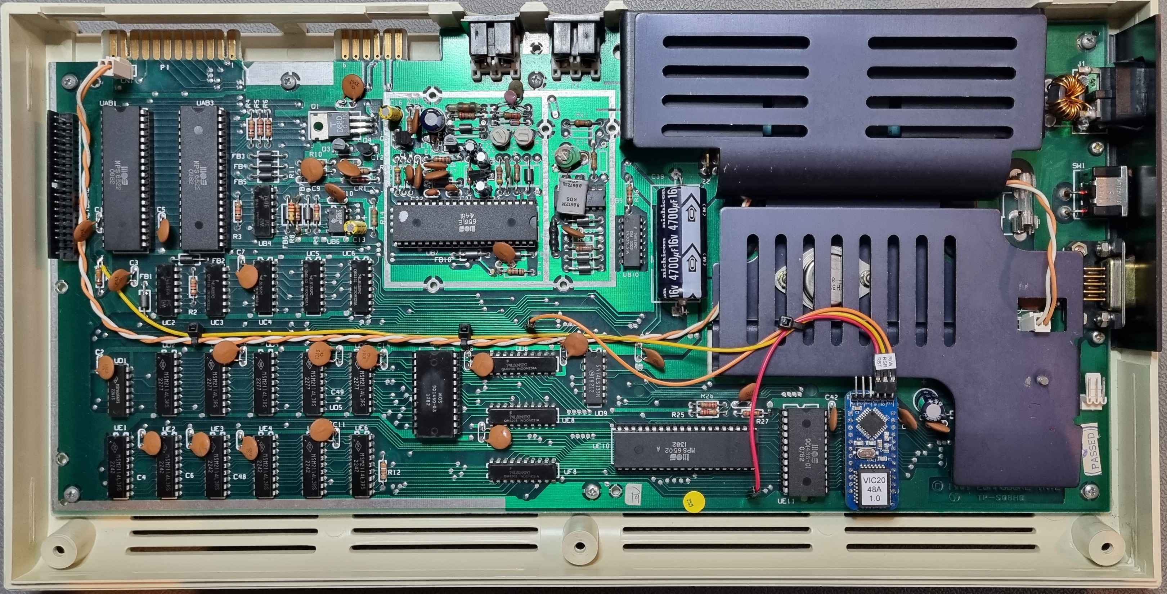
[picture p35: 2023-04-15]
applications/Switchless multi-kernal for VIC-20/images/324003_installation.jpg

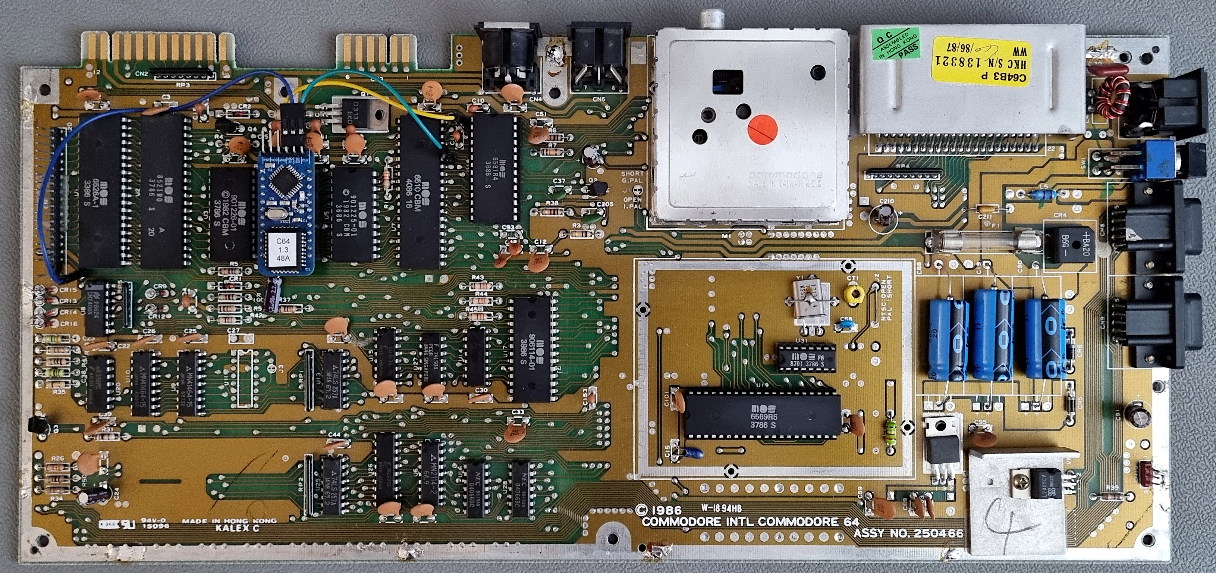
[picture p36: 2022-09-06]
applications/Switchless multi-kernal for C64 longboard/images/250466_installation.jpg

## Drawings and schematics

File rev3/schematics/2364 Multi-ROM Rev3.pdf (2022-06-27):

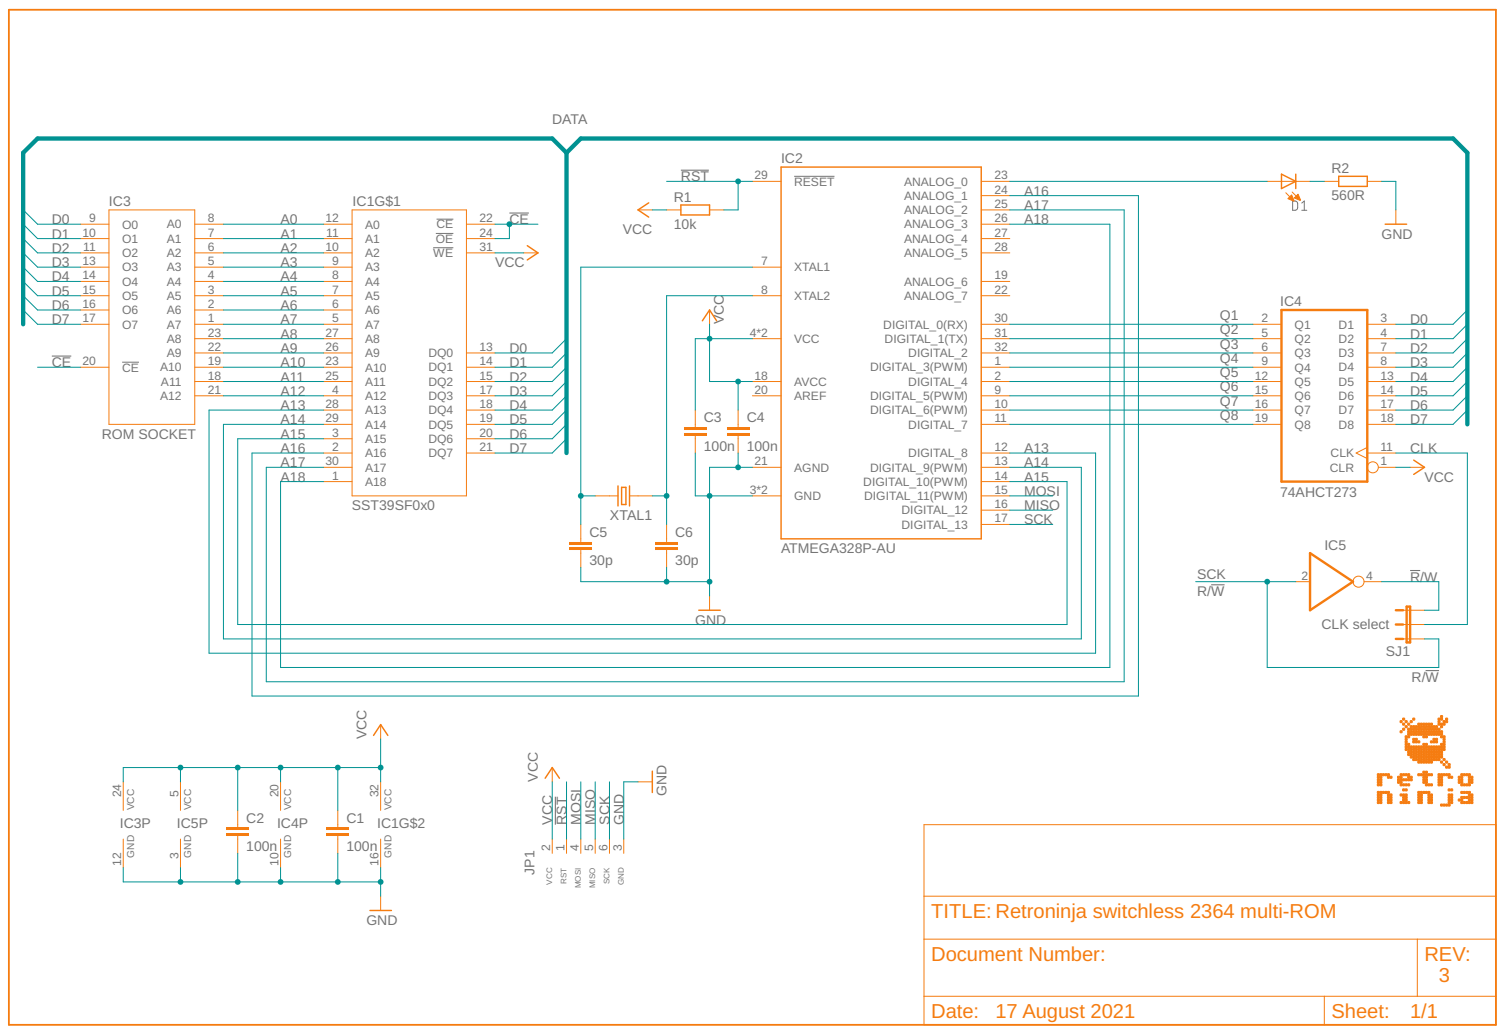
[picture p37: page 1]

SCK RST VCC MOSI GND

Retroninja switchless 2364 multi-ROM

Document Number: | REV: 3

Date: 17 August 2021 | Sheet: 1/1

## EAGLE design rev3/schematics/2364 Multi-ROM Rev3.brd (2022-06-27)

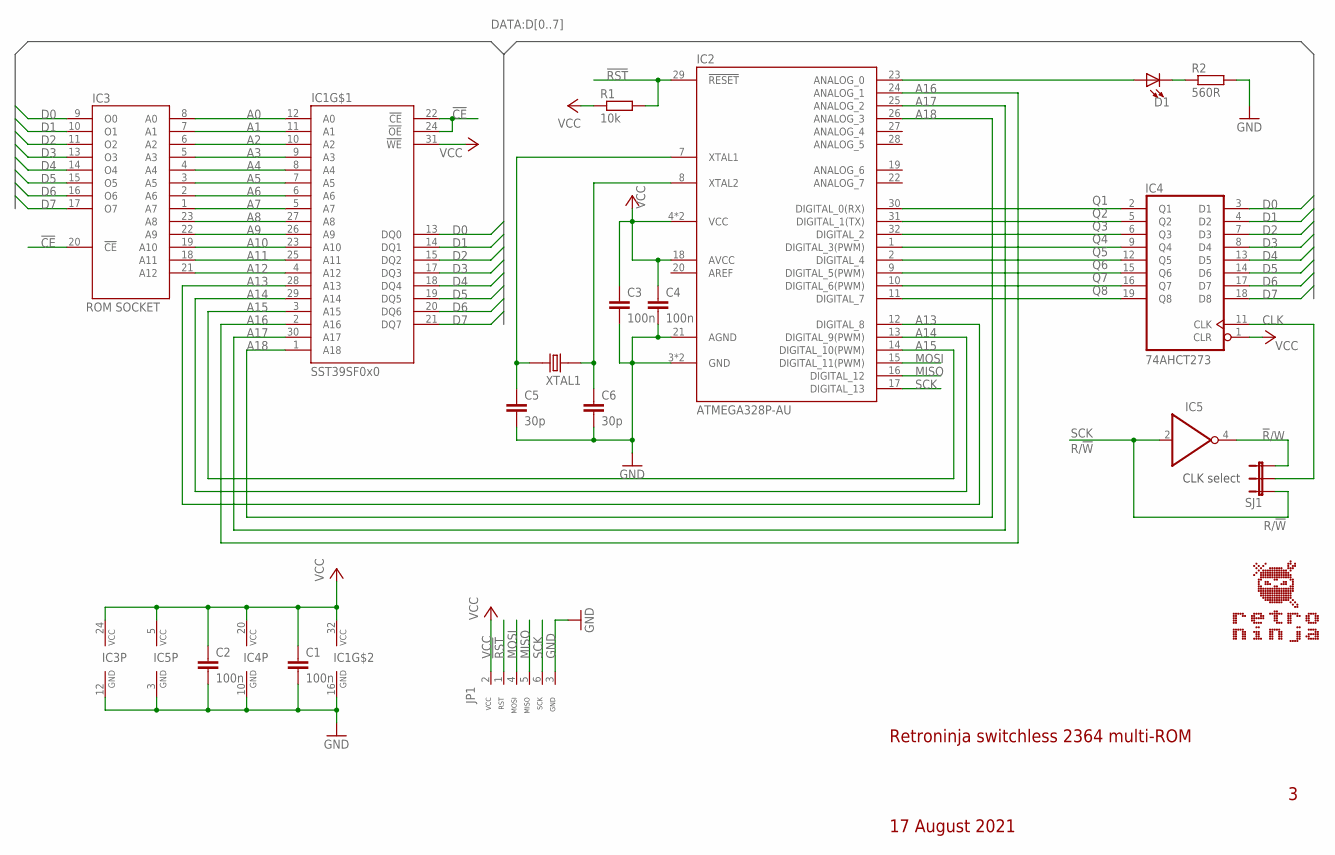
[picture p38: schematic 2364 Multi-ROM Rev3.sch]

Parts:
C1, C2, C3, C4: 100n; C0805
C5, C6: 30p; C0805
D1: LED_0805; LED0805
IC1: SST39SF0x0; PLCC32_SHORT
IC2: ATMEGA328P-AU; TQFP32
IC3: ROM SOCKET; DIL24-6_DOWNPINS
IC4: 74AHCT273; SO20
IC5: 741G04_SOT23; SOT23-5
JP1: ICSP_CONNECTOR_TL866_RIGHT2; HEADER_1X6_RIGHT
R1: 10k; R0805
R2: 560R; R0805
SJ1: JUMPER-3SJ; SJ-3
XTAL1: CRYSTAL; CRYSTAL_SMD-2_7X4X2.3

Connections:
!CE: IC1.22 (!CE), IC1.24 (!OE), IC3.20 (!CE)
!R!/W: IC5.4 (O), SJ1.3
!RST: IC2.29 (!RESET), JP1.1 (RST), R1.2
A0: IC1.12 (A0), IC3.8 (A0)
A1: IC1.11 (A1), IC3.7 (A1)
A2: IC1.10 (A2), IC3.6 (A2)
A3: IC1.9 (A3), IC3.5 (A3)
A4: IC1.8 (A4), IC3.4 (A4)
A5: IC1.7 (A5), IC3.3 (A5)
A6: IC1.6 (A6), IC3.2 (A6)
A7: IC1.5 (A7), IC3.1 (A7)
A8: IC1.27 (A8), IC3.23 (A8)
A9: IC1.26 (A9), IC3.22 (A9)
A10: IC1.23 (A10), IC3.19 (A10)
A11: IC1.25 (A11), IC3.18 (A11)
A12: IC1.4 (A12), IC3.21 (A12)
A13: IC1.28 (A13), IC2.12 (DIGITAL_8)
A14: IC1.29 (A14), IC2.13 (DIGITAL_9(PWM))
A15: IC1.3 (A15), IC2.14 (DIGITAL_10(PWM))
A16: IC1.2 (A16), IC2.24 (ANALOG_1)
A17: IC1.30 (A17), IC2.25 (ANALOG_2)
A18: IC1.1 (A18), IC2.26 (ANALOG_3)
CLK: IC4.11 (CLK), SJ1.2
D0: IC1.13 (DQ0), IC3.9 (O0), IC4.3 (D1)
D1: IC1.14 (DQ1), IC3.10 (O1), IC4.4 (D2)
D2: IC1.15 (DQ2), IC3.11 (O2), IC4.7 (D3)
D3: IC1.17 (DQ3), IC3.13 (O3), IC4.8 (D4)
D4: IC1.18 (DQ4), IC3.14 (O4), IC4.13 (D5)
D5: IC1.19 (DQ5), IC3.15 (O5), IC4.14 (D6)
D6: IC1.20 (DQ6), IC3.16 (O6), IC4.17 (D7)
D7: IC1.21 (DQ7), IC3.17 (O7), IC4.18 (D8)
GND: C1.2, C2.2, C3.2, C4.2, C5.2, C6.2, IC1.16 (GND), IC2.3 (GND), IC2.5 (GND), IC2.21 (AGND), IC3.12 (GND), IC4.10 (GND), IC5.3 (GND), JP1.3 (GND), R2.2
MISO: IC2.16 (DIGITAL_12), JP1.5 (MISO)
MOSI: IC2.15 (DIGITAL_11(PWM)), JP1.4 (MOSI)
unnamed: C6.1, IC2.8 (XTAL2), XTAL1.1
unnamed: C5.1, IC2.7 (XTAL1), XTAL1.2
unnamed: D1.A, IC2.23 (ANALOG_0)
unnamed: D1.C, R2.1
Q1: IC2.30 (DIGITAL_0(RX)), IC4.2 (Q1)
Q2: IC2.31 (DIGITAL_1(TX)), IC4.5 (Q2)
Q3: IC2.32 (DIGITAL_2), IC4.6 (Q3)
Q4: IC2.1 (DIGITAL_3(PWM)), IC4.9 (Q4)
Q5: IC2.2 (DIGITAL_4), IC4.12 (Q5)
Q6: IC2.9 (DIGITAL_5(PWM)), IC4.15 (Q6)
Q7: IC2.10 (DIGITAL_6(PWM)), IC4.16 (Q7)
Q8: IC2.11 (DIGITAL_7), IC4.19 (Q8)
SCK: IC2.17 (DIGITAL_13), IC5.2 (I), JP1.6 (SCK), SJ1.1
VCC: C1.1, C2.1, C3.1, C4.1, IC1.31 (!WE), IC1.32 (VCC), IC2.4 (VCC), IC2.6 (VCC), IC2.18 (AVCC), IC3.24 (VCC), IC4.1 (CLR), IC4.20 (VCC), IC5.5 (VCC), JP1.2 (VCC), R1.1

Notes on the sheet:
R/!W
Retroninja switchless 2364 multi-ROM
17 August 2021
CLK select

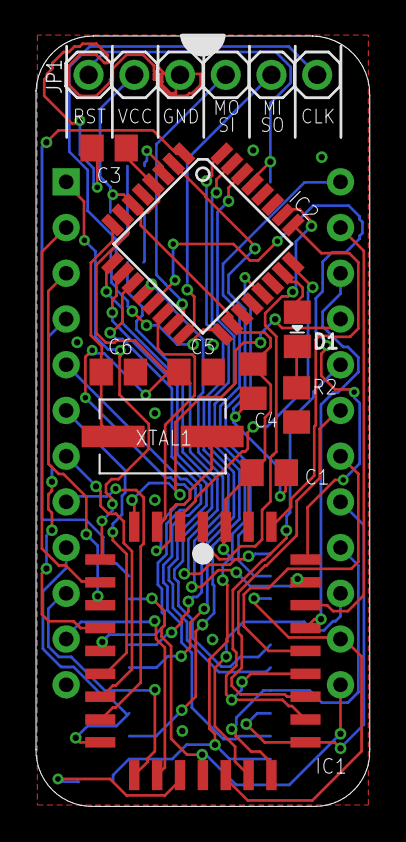
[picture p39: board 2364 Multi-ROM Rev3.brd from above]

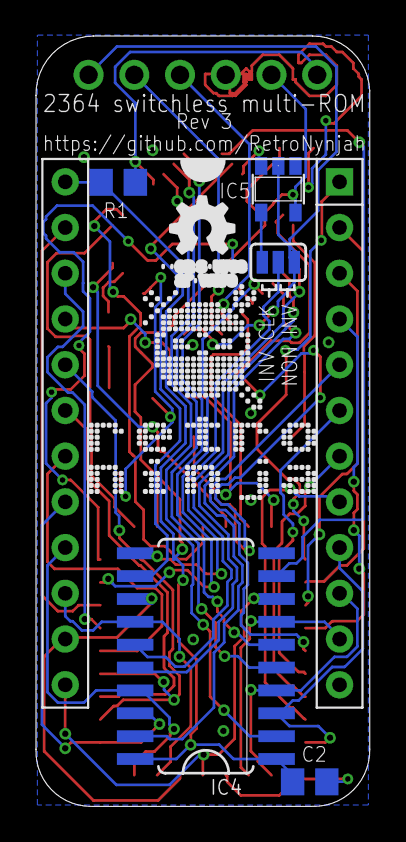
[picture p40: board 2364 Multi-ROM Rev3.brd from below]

Board: 2 copper layers, 18.5 x 42.8 mm, 19 parts (7 on the bottom side), 48 nets.

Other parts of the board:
U$1: RETRONINJA_12MM
U$2: OSHW_5MM

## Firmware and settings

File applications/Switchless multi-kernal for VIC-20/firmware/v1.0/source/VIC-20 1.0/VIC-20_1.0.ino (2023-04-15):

/*
#########################################################################################
#                                                                                       #
#  Kernal switcher sketch for VIC-20 (24-pin ROM)                                       #
#  To be used with the Retroninja 2364 switchless multi-ROM                             #
#                                                                                       #
#  Version 1.0                                                                          #
#  https://github.com/retronynjah                                                       #
#                                                                                       #
#########################################################################################
*/

#include <EEPROM.h>

// searchString is the command that the kernalselector firmware sends to the ROM switcher.
// Searchstring below is RNROM20#
// The command will be followed by a single byte ROM number between 1 (0x01) and 15 (0x0f)
byte searchString[] = {0x52,0x4E,0x52,0x4F,0x4D,0x32,0x30,0x23}; // "RNROM20#"

// pin defitions
int resetPin = 11;
int restorePin = 12;
int clockPin = 13;
int ledPin = A0;

int savedROM;
int commandLength = sizeof(searchString);
int bytesCorrect = 0;
int blinkROM = 0;
bool ledstate = LOW;
long ledchange = 0;
volatile bool clockstate;
bool restorestate;
bool restoreholding = false;
bool inmenu = false;
long restorepressed;

void pciSetup(byte pin) {
  // enable Pin Change Interrupt for requested pin
  *digitalPinToPCMSK(pin) |= bit(digitalPinToPCMSKbit(pin));  // enable pin
  PCIFR |= bit(digitalPinToPCICRbit(pin));                    // clear any outstanding interrupt
  PCICR |= bit(digitalPinToPCICRbit(pin));                    // enable interrupt for the group
}



ISR(PCINT0_vect)  // handle pin change interrupt for D8 to D13 here
{
  // read state of clock pin (D13)
  clockstate = PINB & B100000;
}


void cleareeprom() {
  for (int i = 0; i < EEPROM.length(); i++) {
    EEPROM.write(i, 0);
  }
}


void switchrom(int romnumber, bool doreset){

  if (doreset){
    // hold reset 
    digitalWrite(resetPin, LOW);
    delay(100);
    pinMode(resetPin, OUTPUT);
    digitalWrite(resetPin, LOW);
  }
 
  // switch eprompin A13 (D8)
  if (romnumber & B0001){
    digitalWrite(8, HIGH);
  }  
  else {
    digitalWrite(8, LOW);
  }

  // switch eprompin A14 (D9)
  if (romnumber & B000010){
    digitalWrite(9, HIGH);
  }  
  else {
    digitalWrite(9, LOW);
  }

  // switch eprompin A15 (D10)
  if (romnumber & B000100){
    digitalWrite(10, HIGH);
  }  
  else {
    digitalWrite(10, LOW);
  }

  // switch eprompin A16 (A1)
  if (romnumber & B001000){
    digitalWrite(A1, HIGH);
  }  
  else {
    digitalWrite(A1, LOW);
  }

  // switch eprompin A17 (A2)
  if (romnumber & B010000){
    digitalWrite(A2, HIGH);
  }  
  else {
    digitalWrite(A2, LOW);
  }

  // switch eprompin A18 (A3)
  if (romnumber & B100000){
    digitalWrite(A3, HIGH);
  }  
  else {
    digitalWrite(A3, LOW);
  }

  // if switching to a new kernal that isn't the menu kernal - save kernal to EEPROM address 0
  if ((romnumber != savedROM) && (romnumber != 0)){
    EEPROM.write(0, romnumber);
    savedROM = romnumber;
  }
  
  if (romnumber != 0){
    inmenu = false;
  }
  
  if (doreset) {
    // Release reset
    delay(200);
    pinMode(resetPin, INPUT);
  }

  // Give system some time to reset before entering main loop again.
  delay(500);
  blinkROM = romnumber;
}


void setup() {

  // set data pins 0..7 as inputs
  DDRD = B00000000;

  // Keep reset active (low) during setup
  digitalWrite(resetPin, LOW);
  pinMode(resetPin, OUTPUT);
  pinMode(clockPin, INPUT);
  
  pinMode(8, OUTPUT); // eprom A13
  pinMode(9, OUTPUT); // eprom A14
  pinMode(10, OUTPUT); // eprom A15
  pinMode (A1, OUTPUT); // eprom A16
  pinMode (A2, OUTPUT); // eprom A17
  pinMode (A3, OUTPUT); // eprom A18
  pinMode (ledPin, OUTPUT);

  pinMode (restorePin, INPUT);
  digitalWrite(ledPin, LOW);
  
  // retrieve last used ROM from ATmega EEPROM and switch ROM using ROM address pins A13-A18
  savedROM = EEPROM.read(0);
  if (savedROM > 15){
    savedROM = 0;
  }
  if (savedROM == 0) {
    inmenu = true;
  }
  
  switchrom(savedROM, false);
  
  // Release reset
  pinMode(resetPin, INPUT);
  delay(500); // Give system some time to finish reset before entering loop

  // Enable pin change interrupt on pin D13(PB5) connected to R/!W signal
  pciSetup(clockPin);
  
}


void loop() {

  if (inmenu) {
    ledstate = LOW;
    blinkROM = 0;
    // while in menu mode, listen for command
    if (clockstate == HIGH) {
      byte byteCurr = PIND;
      clockstate = LOW;
      if (bytesCorrect == commandLength) {
        // We have already found our command string. This byte must be the ROM number
        // Valid numbers are 1-15
        if ((byteCurr >= 1) && (byteCurr <= 15)) {
          // ROM number within valid range. Switch ROM and perform a reset
          switchrom(byteCurr, true);
        } else {
          bytesCorrect = 0;
        }
      }
      // We don't have full command string yet. Check if current byte is what we are looking for
      else if (byteCurr == searchString[bytesCorrect]) {
        // Increase bytesCorrect to check for next character
        bytesCorrect++;
      } else {
        bytesCorrect = 0;
      }
    }

    // Check if reset pin is active (low)
    if (!(PINB & B1000)) {
      // Reset is active. Other switch might be active and doing a reset or user is resetting.
      // Switch ROM to give up menu in case we're in menu and don't perform another reset as a reset is already in progress.
      switchrom(savedROM, false);
    }
  } else {
    // while not in menu mode, listen for restore key
    restorestate = PINB & B010000;
    if (restorestate == LOW) {
      // restore pressed
      ledstate = HIGH;
      if (restoreholding == false) {
        // start counting restore hold time
        restorepressed = millis();
        restoreholding = true;
      }
      if ((millis() - restorepressed) > 2000) {
        // Switch to menu ROM and perform a reset
        inmenu = true;
        switchrom(0, true);
        ledstate = LOW;
        restoreholding = false;
      }
    } else {
      // restore not held
      if (restoreholding){
        // restore has just been released
        ledstate = LOW;
        restoreholding = false;
      }
      
      //if kernal has just been switched we can do some led blinking now to indicate selected kernal
      if (blinkROM > 0) {
        if (ledchange == 0) {
          // first blink turn on LED and start counting
          ledstate = HIGH;
          ledchange = millis() + 50;
        } else {
          if (millis() > ledchange) {
            // time to toggle LED
            if (ledstate == HIGH) {
              ledstate = LOW;
              blinkROM--;
              if (blinkROM > 0) {
                // turn off LED and start counting
                ledchange = millis() + 250;
              } else {
                ledchange = 0;
              }
            } else {
              // turn on LED and start counting
              if (blinkROM > 0) {
                ledstate = HIGH;
                ledchange = millis() + 50;
              }
            }
          }
        }
      } 
    }
    digitalWrite(ledPin, ledstate);
  }
}

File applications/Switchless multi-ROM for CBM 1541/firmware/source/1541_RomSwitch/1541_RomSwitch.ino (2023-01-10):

/*
#########################################################################################
#                                                                                       #
#  ROM switcher sketch for CBM 1541 (24-pin ROM)                                        #
#  To be used with the Retroninja 2364 switchless multi-ROM                             #
#                                                                                       #
#  Version 1.2                                                                          #
#  https://github.com/retronynjah                                                       #
#                                                                                       #
#########################################################################################
*/

#include <EEPROM.h>

// searchString is the command that is used for switching ROM.
// It is passed by the 1541 in reverse order so the variable should be reversed too.
// The command should be preceded by a ROM number between 1 and 4 when used.
// The below reversed searchString in hex ascii is MORNR@ which is specified like this on the C64: 1@RNROM, 2@RNROM and so on.
byte searchString[] = {0x4D,0x4F,0x52,0x4E,0x52,0x40};

// pin defitions
int resetPin = 11;
int clockPin = 13;
int ledPin = A0;

int commandLength = sizeof(searchString);
int bytesCorrect = 0;
volatile bool state;
static byte byteCurr;


void pciSetup(byte pin)
{
    // enable Pin Change Interrupt for requested pin
    *digitalPinToPCMSK(pin) |= bit (digitalPinToPCMSKbit(pin));  // enable pin
    PCIFR  |= bit (digitalPinToPCICRbit(pin)); // clear any outstanding interrupt
    PCICR  |= bit (digitalPinToPCICRbit(pin)); // enable interrupt for the group
}



ISR (PCINT0_vect) // handle pin change interrupt for D8 to D13 here
{    
       // read state of pin 13
       state = PINB & B100000;
}
 

void cleareeprom(){
  for (int i = 0 ; i < EEPROM.length() ; i++) {
    EEPROM.write(i, 0);
  }
}


void resetdrive(){
  pinMode(resetPin, OUTPUT); // reset pin
  digitalWrite(resetPin, LOW);
  delay(50);
  digitalWrite(resetPin, HIGH);
  delay(50);
  digitalWrite(resetPin, LOW);
  pinMode(resetPin, INPUT);

}


void switchrom(int romnumber){

  // switch eprompin A13 (D8)
  if (romnumber & B0001){
    digitalWrite(8, HIGH);
  }  
  else {
    digitalWrite(8, LOW);
  }

  // switch eprompin A14 (D9)
  if (romnumber & B000010){
    digitalWrite(9, HIGH);
  }  
  else {
    digitalWrite(9, LOW);
  }

  // switch eprompin A15 (D10)
  if (romnumber & B000100){
    digitalWrite(10, HIGH);
  }  
  else {
    digitalWrite(10, LOW);
  }

  // switch eprompin A16 (A1)
  if (romnumber & B001000){
    digitalWrite(A1, HIGH);
  }  
  else {
    digitalWrite(A1, LOW);
  }

  // switch eprompin A17 (A2)
  if (romnumber & B010000){
    digitalWrite(A2, HIGH);
  }  
  else {
    digitalWrite(A2, LOW);
  }

  // switch eprompin A18 (A3)
  if (romnumber & B100000){
    digitalWrite(A3, HIGH);
  }  
  else {
    digitalWrite(A3, LOW);
  }


  int savedROM = EEPROM.read(0);
  if (savedROM != romnumber){
    EEPROM.write(0, romnumber);
  }

  resetdrive();

  // blink LED to indicate selected image
  for (int x = 0; x <= romnumber; x++){
    digitalWrite (ledPin, HIGH);
    delay(30);
    digitalWrite (ledPin, LOW);
    delay(250);
  }
  delay (200);
}




void setup() {

  // set data pins as inputs
  DDRD = B00000000;
  
  pinMode(clockPin, INPUT); // R/!W
  pinMode(resetPin, INPUT); // Keep reset pin as input while not performing reset.
  
  pinMode(8, OUTPUT); // eprom A13
  pinMode(9, OUTPUT); // eprom A14
  pinMode(10, OUTPUT); // eprom A15
  pinMode(A1, OUTPUT); // eprom A16
  pinMode(A2, OUTPUT); // eprom A17
  pinMode(A3, OUTPUT); // eprom A18

  pinMode (ledPin, OUTPUT);
    
  // retrieve last used ROM from ATmega EEPROM and switch ROM using ROM address pins A13-A16
  int lastROM = EEPROM.read(0);
  if (lastROM > 8){
    cleareeprom();
    lastROM = 0;
  }
  switchrom(lastROM);
  
  // enable pin change interrupt on pin D13(PB5) connected to R/W (pin 34) on 6502
  pciSetup(clockPin); 
}


void loop() {
  if (state == HIGH){
    byteCurr = PIND;
    state=LOW;
      
    // we don't have full search string yet. check if current byte is what we are looking for
    if (byteCurr == searchString[bytesCorrect]){
      // It is the byte we're waiting for. increase byte counter
      bytesCorrect++;
      if (bytesCorrect == commandLength){
        // we have our full search string. wait for next byte
        while(state == LOW){}
        byteCurr = PIND;
        // This byte should be the ROM number
        // valid numbers are 1-4 (ASCII 49-52)
        if ((byteCurr >= 49)&&(byteCurr<=52)){
              // rom number within valid range. Switch rom
              switchrom(byteCurr - 49);
        }
        else if(byteCurr == searchString[0]){
              // it was the first byte in string, starting with new string
              bytesCorrect = 1;
        }
        else{
          bytesCorrect = 0;
        }
      }
    }
    // byte isn't what we are looking for, is it the first byte in the string then?
    else if(byteCurr == searchString[0]){
        // it was the first byte in string, starting with new string
        bytesCorrect = 1;
    }
    else {
      // byte not correct at all. Start over from the beginning
      bytesCorrect = 0;
    }
  }
}

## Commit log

2022-06-27 Initial upload
    [2364 Multi-ROM Rev3.brd, 2364 Multi-ROM Rev3.sch]
2022-07-07 CBM 1541 Firmware v1.1
    New firmware that matches PCB rev3.
2022-09-06 Updated Kernal Switch pictures and corrected user guide version
2022-09-07 Updated Kernal switch user guide
    Kernal switch user guide version 1.2 with Kernal ROM chip location and socket information
2022-10-04 BOM corrected in technical guide
2023-01-03 Firmware v1.4 for C64 Kernal switch
    Version numbers aligned between firmware for different Kernal switches as functionality is the pretty much same for all switches.
    Improved handling of restore key functionality while in menu. This was originally done for the C128 Kernal switch but was ported to the C64 firmware to keep them as similar as possible.
    Code cleanup and some optimizations of main loop.
    Thanks Pär Högberg!
2023-01-09 Moved 1541 ROM switch firmware files
2023-01-10 New firmware version 1.2
    Incorporated reworked and optimized code and a number of fixes from the ROM-switch for 28-pin ROMs.
    Thanks to Pär Högberg for contributing code optimizations.
    [1541_RomSwitch.ino]
2023-04-15 Added VIC-20 Kernal switch
2023-08-27 Update vic20kernalmenu.bin
    Minor correction in menu settings of mini-kernal sample
2023-08-28 VIC-20 mini-kernal sample updated
    Updated kernal menu settings. No code changes-
2024-10-01 VIC-20 PCB 251037
    Added pictures of PCB 251037
